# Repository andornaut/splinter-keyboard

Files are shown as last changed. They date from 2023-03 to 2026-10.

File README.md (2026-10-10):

# Splinter keyboard




A 62-key split columnar ergonomic keyboard.

This repo holds the hardware design files; firmware lives in a [separate repo](https://github.com/andornaut/qmk_firmware/tree/splinter/keyboards/splinter). Design pipeline: Keyboard Layout Editor -> Ergogen -> KiCad -> fabrication -> Onshape -> OrcaSlicer -> QMK (see [Developing](#developing)).

Related notes: [3D printing](https://github.com/andornaut/til/blob/main/docs/3d-printing.md), [electronics](https://github.com/andornaut/til/blob/main/docs/electronics.md), [keyboards](https://github.com/andornaut/til/blob/main/docs/keyboards.md).

## Versions

| Version | MCU | Changes from previous | Firmware | Photo |
| --- | --- | --- | --- | --- |
| [v4](./v4) | [splitkb Liatris](https://splitkb.com/products/liatris) (RP2040) | Added USB VBUS detection and TRRS data-line protection | [splinter](https://github.com/andornaut/qmk_firmware/tree/splinter/keyboards/splinter) | Pending |
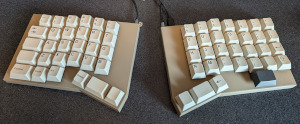
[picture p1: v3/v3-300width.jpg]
v3
| [v3](./v3) | [Adafruit KB2040](https://www.adafruit.com/product/5302) (RP2040) | Switched from AVR to RP2040 | [splinter-3.0](https://github.com/andornaut/qmk_firmware/tree/splinter-3.0/keyboards/splinter) |  |
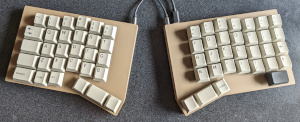
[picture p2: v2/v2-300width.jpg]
v2
| [v2](./v2) | [SparkFun Pro Micro](https://www.sparkfun.com/sparkfun-qwiic-pro-micro-usb-c-atmega32u4.html) (ATmega32U4) | Symmetrical enclosures; added a key (62 keys) | [splinter-2.0](https://github.com/andornaut/qmk_firmware/tree/splinter-2.0/keyboards/splinter) |  |
| [v1](./v1) | [SparkFun Pro Micro](https://www.sparkfun.com/sparkfun-qwiic-pro-micro-usb-c-atmega32u4.html) (ATmega32U4) | Initial version: 61 keys, columnar layout, asymmetrical enclosures | [splinter-1.0](https://github.com/andornaut/qmk_firmware/tree/splinter-1.0/keyboards/splinter) | v1 |

## Repository layout

Every version directory (`v1/` .. `v4/`) follows the same shape, though not every version has every part:

| Path | Contents |
| --- | --- |
| `ergogen/config.yaml` | Keyboard definition. The source of truth for everything downstream. |
| `ergogen/footprints/` | Symlink to the shared footprints below, so every version builds against one pinned set. Do not edit. |
| `keyboard-layout-editor/` | Layout prototypes. |
| `kicad/unrouted/` | Working boards. Ergogen generates into these; you route here. |
| `kicad/routed/` | Routed masters. The fab source. |
| `kicad/unrouted-backups/` | Timestamped copies of the `unrouted/` boards, taken each time fresh ones overwrite them. Gitignored, and only the last few per board are kept. |
| `kicad/jlcpcb-parts.json` | LCSC part numbers, kept outside the `.kicad_pcb` so they survive regeneration. v4 only, and what makes assembly files appear. |
| `onshape/` | Case design. v1 to v3 keep their exported STEP here. v4 commits none, carrying the build sheet, the rationale, and a script that builds the same design as geometry; generate or export to `dist/`. |
| `orcaslicer/` | Slicer projects. v2 and v3 only. |

Shared across versions:

| Path | Contents |
| --- | --- |
| `ergogen/` | Footprints and helpers. |
| `scripts/` | Build steps. |
| `dist/` | Build output. Generated, not committed. |

A `_` prefix on a PCB filename excludes it from every step.

## Installation

| Tool | Needed for |
| --- | --- |
| [KiCad 10](https://www.kicad.org) | Routing, and `kicad-cli` for gerber export and headless DRC |
| [Node.js](https://nodejs.org/en) | Ergogen and the npm scripts |
| [Python 3](https://www.python.org) | The build steps (stdlib only; `pcbnew` comes from KiCad) |
| [OrcaSlicer](https://github.com/OrcaSlicer/OrcaSlicer) | Slicing the printed case |
| [FreeCAD](https://www.freecad.org) | `freecadcmd`, for [validating the case export](#step-6-onshape) |
| [Freerouting](https://github.com/freerouting/freerouting) | Optional, for [autorouting](#autorouting-optional) |
| [KiKit](https://github.com/yaqwsx/KiKit) | Optional, for [panelization](#panelization-optional-for-pcba-cost); needs the git-master build |

```bash
# Include submodules when cloning
git clone --recursive git@github.com:andornaut/splinter-keyboard.git
cd splinter-keyboard

# Install the Node version from .nvmrc, then the deps (including Ergogen)
nvm install
npm install

# Install KiCad 10 (provides kicad-cli, used for fab file generation)
sudo add-apt-repository ppa:kicad/kicad-10.0-releases
sudo apt install kicad

# Fallback only if you cloned without --recursive
git submodule update --init --recursive
```

OrcaSlicer, FreeCAD, KiCad, Freerouting and KiKit also install from [these Ansible tasks](https://github.com/andornaut/ansible-ctrl/blob/main/roles/hobbies/tasks/main.yml) (tags `orcaslicer`, `freecad` and `kicad`; Freerouting and KiKit come with `kicad`).

**Updating footprint submodules.** `npm run ergogen` uses `ceoloide` and `infused-kim` at their pinned revision and never advances them, so builds stay reproducible. To re-pin:

```bash
git submodule update --remote ergogen/footprints/ceoloide ergogen/footprints/infused-kim
git add ergogen/footprints/ceoloide ergogen/footprints/infused-kim
git commit -m "Bump footprint submodules"
```

## Commands

Run everything through `npm run` from the repo root: the scripts read the active version from `config.VERSION` in [`package.json`](./package.json).

| Command | Does |
| --- | --- |
| `pipeline` | The full build, every gate in order. The normal entry point. Add `-- -v` for the full log. |
| `ergogen` | Generate outlines and PCBs into `dist/${VERSION}/ergogen/` |
| `watch` / `watch:sync-unrouted` | Re-run `ergogen` on every `config.yaml` change, the second also copying into `unrouted/` |
| `copy:dist-to-unrouted` | `dist/` -> `unrouted/` (backs the old boards up to `unrouted-backups/` first) |
| `copy:traces-to-unrouted` | Traces and teardrops from `routed/` back into `unrouted/` |
| `copy:unrouted-to-routed` | `unrouted/` -> `routed/` (see [Saving to routed/](#saving-to-routed)) |
| `fab` | Gerbers, drill, and assembly BOM/CPL via `kicad-cli` |
| `panelize` | Combine both halves into one JLCPCB panel (optional) |
| `route` | Autoroute `unrouted/` via Freerouting (optional) |
| `validate:provenance` / `validate:symmetry` / `validate:firmware` / `validate:fab` | The four gates (see [Validation](#validation)) |
| `clean` | Remove `dist/` |
| `lint` / `format` | Prettier and ESLint, checking or fixing. `lint` is a CI gate |

## Developing

### Step 1. Configure

Set `config.VERSION` in [`package.json`](./package.json) to `v1`, `v2`, `v3`, or `v4`, by editing the file or with `npm pkg set config.VERSION=v4`.

### Step 2. [Keyboard Layout Editor](https://www.keyboard-layout-editor.com/)

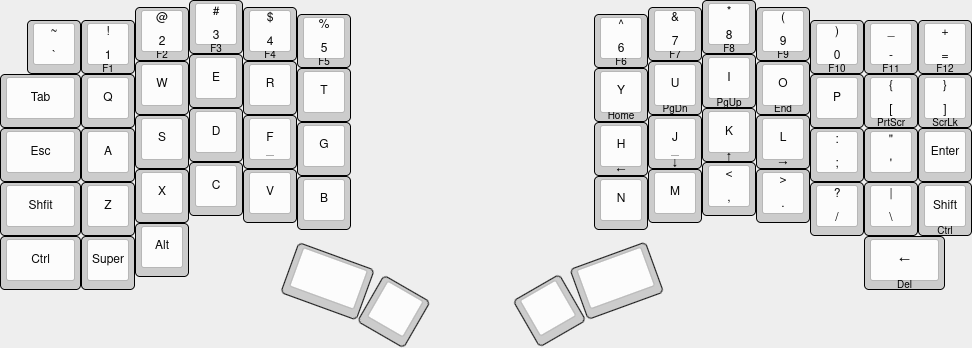
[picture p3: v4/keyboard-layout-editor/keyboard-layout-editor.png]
Keyboard Layout preview


Prototype a layout, export it to [`keyboard-layout-editor.json`](./v4/keyboard-layout-editor/keyboard-layout-editor.json) so you can re-import and iterate, then use it as the basis for the Ergogen design.

### Step 3. [Ergogen](https://github.com/ergogen/ergogen)

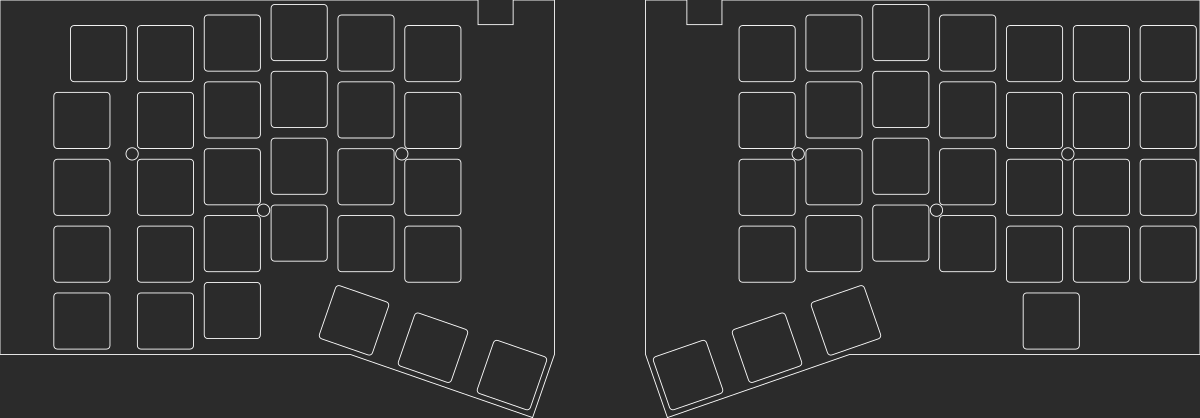
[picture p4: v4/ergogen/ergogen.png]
Ergogen preview


1. `docker compose up` starts the Ergogen GUI (it builds on first run); open <http://ergogen.internal> (needs [docker_etc_hosts](https://github.com/andornaut/docker_etc_hosts) for the `/etc/hosts` entry).
1. Paste in, edit, then download [`ergogen/config.yaml`](./v4/ergogen/config.yaml).
1. `npm run ergogen`, then `npm run copy:dist-to-unrouted`. Or just `npm run watch:sync-unrouted`.

- The GUI renders no PCBs and is client-side only. Edit there, copy back to `config.yaml` (the source of truth), build with `npm run ergogen`.
- The browser cannot load footprints from disk, so the [`Dockerfile`](./Dockerfile) bakes this repo's [custom footprints](./ergogen/footprints/) into the GUI image. An unregistered `what:` shows up as unknown; after adding one, `docker compose build --no-cache`.

### Step 4. [KiCad](https://www.kicad.org/)

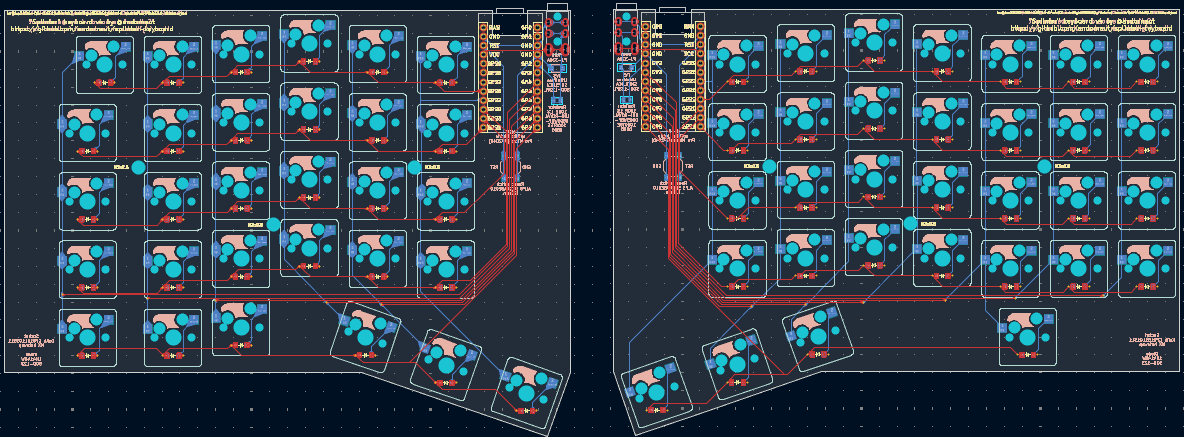
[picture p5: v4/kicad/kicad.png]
KiCad preview


Open a board from [`kicad/unrouted/`](./v4/kicad/unrouted/) and route it. Before saving:

- **Add teardrops** (Edit > Edit Teardrops, nothing selected for board-wide): stronger pad and via joints. Re-run after any reroute.
- **Run DRC** (Inspect > Design Rules Checker, "Refill all zones" checked): clear every violation and unrouted net. `npm run fab` re-runs it headlessly, but fixing it here beats reading the JSON.
- **Check copper and silk** visually: no isolated GND islands or stranded pads; silk clear of pads and the board edge.

After regenerating with Ergogen, `npm run copy:traces-to-unrouted` brings the traces and teardrops from `routed/` back into `unrouted/` (then File > Revert in KiCad).

#### Saving to routed/

`npm run copy:unrouted-to-routed` writes the masters' `.kicad_pro` and `.kicad_dru` first, since the stages that move copper measure against the clearances those hold. Then, one master at a time, it copies the working board onto its master in [`kicad/routed/`](./v4/kicad/routed/) and runs:

| Stage | What it does |
| --- | --- |
| GND pour | Floods a ground plane on whichever side costs less (scored per board, F.Cu vs B.Cu) |
| Cleanup | Strips copper no route uses: dangling tracks and the vias they strand, tracks buried in pads, redundant vias, split segments |
| Pattern snap | Pulls strays onto the repeated shape they belong to, within a per-endpoint cap |
| Sliver tidy  | Collapses any segment left shorter than it is wide, within a per-endpoint cap |

One master at a time, copy included, because any stage can stop the build: a master this run has not reached yet is still the routed board it was, rather than an un-poured working copy that nothing downstream would catch.

The last three stages feed each other: a collapsed sliver can leave a run the next snap recognises, and a snap leaves fragments for the next cleanup to merge and can leave a sliver of its own. So they repeat until a pass changes nothing, and a board still changing on the last allowed pass stops the build instead of shipping a master its own tooling has not finished with.

The working boards keep the stripped copper, mainly the footprints' unused `include_traces_vias` stubs, since a later reroute may pick it up.

Pattern snap and sliver tidy move copper rather than only removing it, so both are capped and both stop the build rather than guess:

- **Pattern snap.** The matrix is a grid, so most of the routing is one motif repeated, and hand-drawn copies land a fraction of a millimetre apart. DRC never sees it, because each copy is individually legal. Anything beyond the cap is a routing decision rather than a stray, so it is reported and left alone.
- **Sliver tidy.** Moving one end of a run pivots the whole run, so a collapse is refused if it exceeds the cap or would swing copper into another net's clearance or a keepout. The refusal names the sliver and the reason; close it in KiCad by dragging the two runs together, or by re-routing clear of the named area.

#### Autorouting (optional)

KiCad has no built-in autorouter. `npm run route` routes the [`unrouted/`](./v4/kicad/unrouted/) boards in place via [Freerouting](https://github.com/freerouting/freerouting), leaving `routed/` untouched; expect to hand-clean the result, then File > Revert. Raising via cost trades vias for _unrouted nets_, so it cannot beat hand-routing on via count.

| Env var | Default | Values |
| --- | --- | --- |
| `FREEROUTING_PASSES` | 100 | |
| `FREEROUTING_STRATEGY` | greedy | greedy, global, hybrid |
| `FREEROUTING_SELECTION` | prioritized | prioritized, random, sequential |
| `FREEROUTING_VIA_COST` | 50 | higher = fewer vias |
| `FREEROUTING_UNDESIRED_DIR_COST` | unset | cost of routing against a layer's preferred direction |
| `FREEROUTING_LOG_LEVEL` | WARN | ERROR, WARN, INFO, DEBUG, TRACE |

### Step 5. Fabrication (JLCPCB)

`npm run fab` exports from `routed/` into `dist/${VERSION}/kicad/jlcpcb/<name>/`:

| Output | Contents |
| --- | --- |
| `<name>-gerber.zip` | Gerbers and drill: the bare PCB |
| `<name>-BOM.csv`, `<name>-CPL.csv` | Assembly files, written only when [`jlcpcb-parts.json`](./v4/kicad/jlcpcb-parts.json) is present |
| `<name>-drc.json` | Headless DRC report, written per board before that board's export. Any error-level violation or unrouted net stops the run there, so a failing board never overwrites its own last-good gerbers. |

A provenance check gates the whole run before any board is touched, so a master that drifted from `config.yaml` produces nothing at all.

Which parts JLCPCB places and which you hand-solder is version-specific; see the [v4 notes](./v4/README.md#fabrication-jlcpcb).

**Ordering** from [JLCPCB](https://jlcpcb.com/): upload each `<name>-gerber.zip`, plus the matching BOM and CPL for assembly. Check placement in the [DFM viewer](https://cart.jlcpcb.com/quote/gerberviewThree); fix a mis-oriented part via its `rotation` in [`jlcpcb-parts.json`](./v4/kicad/jlcpcb-parts.json) and re-run.

#### Panelization (optional, for PCBA cost)

`npm run panelize` combines `left` and `right` into one panel so JLCPCB's per-order assembly setup and stencil fees are paid once instead of twice: worth it for PCBA orders, skip it for bare boards. Outputs to `dist/${VERSION}/kicad/jlcpcb/panel/`; the per-half `fab` remains the strict DRC gate. Requires [KiKit](https://github.com/yaqwsx/KiKit) (git-master build for KiCad 10); point it at an interpreter with `KIKIT_PYTHON`.

### Step 6. [Onshape](https://cad.onshape.com)

1. Create a document and start a sketch.
1. Select "Insert a DXF or DWG file" > "Import ..." (bottom of the dialog) > `dist/${VERSION}/ergogen/outlines/full_unfilleted.dxf`. That is the nominal hull rather than the fabricated edge: the fillet only removes material, so a pocket cut to the hull can never come out undersized.
1. Design the case to [`onshape/BUILD.md`](./v4/onshape/BUILD.md), which carries every dimension and the feature-by-feature recipe, then export `*.step` files to `dist/${VERSION}/onshape/`. They are build output and are not committed, so a stale one cannot sit in the repo looking like the thing to order.
1. Validate each half's export against the reference, `FC_HALF=left FC_COMPARE=dist/${VERSION}/onshape/<export>.step freecadcmd v4/onshape/gen-case.py`, and decide every difference it reports: move the model to the reference, record it in `v4/onshape/differences.json` as intentional, or fix it as an error. See [Validating your model](./v4/onshape/BUILD.md#validating-your-model).

### Step 7. [OrcaSlicer](https://github.com/OrcaSlicer/OrcaSlicer)

1. Open or create a project and import the `*.step` files from `dist/${VERSION}/onshape/`.
1. Slice and print the case.
1. Install an [M2.5 heat-set insert](https://cnckitchen.store/products/gewindeeinsatz-threaded-insert-m2-5-standard-100-stk-pcs) into each mounting boss with a soldering iron, then clamp the PCB with the [M2.5 screws](./v4/README.md#bill-of-materials-bom).

#### Alternative: machined aluminium case (JLCCNC)

Upload each half's `*.step` to [JLCCNC](https://jlccnc.com) (left and right are separate mirrored parts, so set quantity per file):

| Setting | Value |
| --- | --- |
| Material | 6061 aluminium (JLCCNC's standard alloy) |
| Surface finish | Bead blasting + matte anodizing; drop the bead blasting for a glossier sheen. Black is the safe color. |
| Tolerance | Default (ISO 2768 medium) |
| Threaded holes | Tap the M2.5 holes directly; the heat-set inserts are for the printed case only |

A STEP file cannot carry threads, so model each hole at the ~2.05mm tap-drill diameter and upload a PDF with an `M2.5x0.45` callout and depth. Every hole shares the thread spec, but not the depth: the two bosses a switch recess overlaps take a shallower hole, so call the depths out per boss from the [build sheet](./v4/onshape/BUILD.md#screw-bosses). In Onshape, a Drawing with a hole callout (right-click the hole edge > Callout) emits it.

### Step 8. [QMK firmware](https://qmk.fm/)

Install the [custom QMK firmware](https://github.com/andornaut/qmk_firmware/tree/splinter/keyboards/splinter).

## Automation

### One-command pipeline

`npm run pipeline` re-syncs already-routed boards after a config change:

| # | Step | Does |
| --- | --- | --- |
| 1 | `ergogen` | Rebuild the boards from `config.yaml` |
| 2 | `copy:dist-to-unrouted` | Fresh boards into `unrouted/`, old ones backed up |
| 3 | `copy:traces-to-unrouted` | Replay the masters' routing onto them |
| 4 | `copy:unrouted-to-routed` | Save back to `routed/` ([details](#saving-to-routed)) |
| 5 | `validate:provenance` | Stamps match `config.yaml` |
| 6 | `validate:symmetry` | The halves are exact mirror images |
| 7 | `validate:firmware` | Boards match the QMK matrix |
| 8 | `fab` | Export gerbers and assembly files |
| 9 | `validate:fab` | Audit those outputs |

Every step is a hard gate. `panelize` runs last and is the only optional one, skipped with a note when KiKit is absent.

A step reports what it changed and what wants reading; lines that only confirm nothing needed doing are held back, since each step's closing `OK:` line already carries the count they would have added up to. `npm run pipeline -- -v` shows them all, plus Ergogen's own narration and the artifact listing file by file.

**It requires existing routed masters** and does not route for you: step 3 replays their traces onto the fresh boards and aborts if a master carries no human routing. For a first route, or when geometry moves enough that the old traces no longer fit, route by hand in KiCad (Step 4).

### Validation

| Gate | Checks |
| --- | --- |
| `validate:provenance` | Every board's stamp still matches `config.yaml`, and the boards in a stage were all built in the same run, so neither a stale master nor a half restored on its own can reach fab |
| `validate:symmetry` | The two halves are exact mirror images: outline, parts, pads, rule areas and silk, compared in each board's own frame so the per-board recentering is not read as asymmetry |
| `validate:firmware` | Both halves wire the MCU header identically, and the matrix they imply equals the QMK `keyboard.json` |
| `validate:fab` | The exported artifacts: a board-spanning GND plane on both master and gerbers, a complete gerber set, a non-empty BOM and CPL with every assembled footprint appearing in the CPL exactly once, outputs no older than their sources, comparable teardrop counts across the halves |

`validate:fab` also warns, without failing, when a master was built from an uncommitted tree: the board is fine, but its recorded commit means nothing, so the warning is expected during ordinary in-progress work.

`validate:symmetry` holds the halves to being exact mirrors of each other. The licensed exception is the keys of the outer pinky columns, which differ by design (the left pinky is 1.5u; the right is 1u plus an extra inner column). Drift here is otherwise invisible: both halves still route, pass DRC, fab and assemble, and it surfaces only as a case that fits one half and rocks on the other, or a clearance that is comfortable on one half and marginal on the other. Both halves are generated from one set of mirrored anchors in `config.yaml`, so a failure is a config change to undo rather than a board to edit.

Three kinds of part are placed in the same orientation on both halves rather than mirrored, because the parts themselves cannot be: an MX switch and its Kailh socket have an asymmetric pin pattern, the matrix diode wires straight to a switch pin and follows it, and the MCU is a module that plugs in one way up. Their pads therefore land at mirrored positions carrying the opposite pin at each. Key _placements_ still mirror exactly, and so does every clearance measured from key geometry; only pad-to-edge distances within a key differ between the halves. Hand routing is not compared at all.

`validate:firmware` reads the `keyboard.json` at `config.FIRMWARE` in [`package.json`](./package.json), which ships as a path to a sibling `qmk_firmware` checkout so the check covers what you are about to flash rather than what is pushed. Without that checkout the step fails and no gerbers are produced; pass `--firmware <url|path>` or set `$SPLINTER_FIRMWARE_JSON` instead.

### Provenance stamp

The copy steps and manual routing let `routed/` drift from `config.yaml`, so you could fab a stale board. `npm run ergogen` stamps each board with a hash of `config.yaml`; `fab` refuses a drifted or unstamped master, and `validate:provenance` checks without fabbing. Clear a mismatch by re-running the pipeline, re-routing if needed.

Restoring or rebuilding one half on its own is invisible to the hash, since identical config bytes hash the same across builds, so `validate:provenance` also requires every board in a stage to carry the same stamp. The two stages are compared separately: `unrouted/` is expected to be newer than `routed/` between an `ergogen` run and the save back to the masters.

A panel inherits its masters' stamp rather than getting one of its own, so its `commit=` names the commit the panelled copper came from. Masters whose stamps disagree stop `panelize`, since a panel merged from two generations of board has no single provenance to report.

Only `config.yaml` is hashed, so a footprint `.js` or Ergogen-version change can move geometry without tripping the check, while a comment-only config edit trips a false "stale".

### Reproducing a previous build

A stamp names the commit the build's _inputs_ came from, never the commit that contains the stamped board: the stamp is written into the board, so it can only name its own parent. To get the boards a stamp describes, check that commit out and rebuild.

```bash
git checkout <the commit= from the stamp>
npm run pipeline
```

Taking `kicad/routed/*.kicad_pcb` straight from that commit instead gives you the _previous_ build's masters. Rebuilding reproduces copper, drill, mask, paste, outline and the assembly files identically; only the `built=` timestamp drawn on the silk and a few microns of teardrop fill tessellation differ.

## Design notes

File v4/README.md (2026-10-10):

# Version 4 of the Splinter keyboard

A 62-key split columnar ergonomic keyboard with symmetrical enclosures and non-traditional backspace and backslash placement.

- [QMK firmware](https://github.com/andornaut/qmk_firmware/tree/splinter/keyboards/splinter)
- Build and fabrication workflow: [root README](../README.md#developing)

Each PCB half:

| Outline | Width | Height |
| --- | --- | --- |
| Un-filleted hull | 160.00 mm | 119.00 mm |
| As fabricated, after the 1.5mm corner fillet | 160.00 mm | 118.59 mm |

The fillet rounds the corners off the height; the straight side edges hold the width. See the [case design notes](./onshape/README.md).

## Changes from v3

| Change | Details |
| --- | --- |
| The [splitkb Liatris](https://splitkb.com/products/liatris) (RP2040) replaces the [Adafruit KB2040](https://www.adafruit.com/product/5302) MCU | [Microcontroller](#microcontroller) |
| A TVS diode and series resistor protect the TRRS serial line from hot-unplug transients | [TRRS data-line protection](#trrs-data-line-protection) |

## Microcontroller

The [splitkb Liatris](https://splitkb.com/products/liatris) wires its USB VBUS line to GP19, so QMK senses USB presence via `USB_VBUS_PIN` instead of the `SPLIT_USB_DETECT` polling loop. That removes the roughly two-second unresponsive window at boot and makes the board more reliable after KVM switches.

The MCU is socketed rather than soldered: each one sits in a pair of Mill-Max 12-pin sockets (see the [BOM](#bill-of-materials-bom)) so it can be removed and reused. It mounts on the bottom of the board, the same side as the diodes, hotswap sockets and the rest of the SMD parts, with its own components facing away from the board so the reset and boot buttons stay reachable. That seating determines which header column each matrix net lands on, so it is not interchangeable with the opposite orientation.

The matching firmware config (the `USB_VBUS_PIN` define and the `development_board` and split settings) lives in the [firmware repo](https://github.com/andornaut/qmk_firmware/tree/splinter/keyboards/splinter).

### Pinout

- [splitkb Liatris pinout](https://docs.splitkb.com/product-guides/liatris/pinout)
- [Custom Ergogen footprint: `mcu_liatris`](../ergogen/footprints/mcu_liatris.js), based on [ceoloide/mcu_nice_nano](../ergogen/footprints/ceoloide/mcu_nice_nano.js) and the [marbastlib KiCad footprint](https://github.com/ebastler/marbastlib)

| Left | | | Right |
| --- | --- | --- | --- |
| P1 (GP0) | | | RAW |
| P0 (GP1) | | | GND |
| GND | | | RST |
| GND | | | VCC |
| P2 (GP2) | | | P21 (GP29) |
| P3 (GP3) | | | P20 (GP28) |
| P4 (GP4) | | | P19 (GP27) |
| P5 (GP5) | | | P18 (GP26) |
| P6 (GP6) | | | P15 (GP22) |
| P7 (GP7) | | | P14 (GP20) |
| P8 (GP8) | | | P16 (GP23) |
| P9 (GP9) | | | P10 (GP21) |

The Liatris also carries five extra bottom pins (GP12 to GP16) that the footprint can place but the matrix does not use.

GP19, the `USB_VBUS_PIN`, is the Liatris's internal VBUS-sense pin rather than a header net, so it is absent from the table. The `P19` row maps to GP27, a separate matrix pin.

Which column is which is set by one parameter, `raw_pin_column` on the [`mcu_liatris`](../ergogen/footprints/mcu_liatris.js) footprint: `front_left` or `front_right`, named from the PCB front. [ergogen/config.yaml](./ergogen/config.yaml) sets it explicitly to `front_right`, the footprint's default. From the back, where the MCU mounts, the columns read the other way round. The table above is `front_right`, the datasheet arrangement. Both halves must share the value, because the Liatris cannot be mirrored.

To check it on a physical board, seat the module and confirm its RAW pin lands on the pad silkscreened RAW. The board silk and the config net names cannot tell you: they move together when the parameter flips.

### Verifying the pin mapping

A board whose matrix nets reach the wrong MCU column is fully routed, shorts nothing, and passes DRC and every other check here. It fails only once an MCU is plugged in, which is after the boards are paid for. `npm run validate:firmware` is the gate for that, and both of its checks are required:

- **Half symmetry.** Both halves must wire the MCU header identically. Halves that disagree mean one of them is backwards.
- **Firmware agreement.** The matrix pins implied by the boards must equal the QMK [keyboard.json](https://github.com/andornaut/qmk_firmware/blob/splinter/keyboards/splinter/keyboard.json), both halves plus the serial pin.

What the checks guarantee is that the two halves agree and that the config's net assignments never silently drift from the firmware's pin arrays. What they cannot prove is that the mapping matches physical reality: both mirrorings of the header produce electrically valid boards, the footprint's silk pin labels are generated from the same table as the pad nets, and the firmware check compares net names through that same table. All three move together under a `raw_pin_column` flip.

Only hardware settles that, and it is settled: the current value, `front_right`, is confirmed on an assembled and working board. Treat it as fixed. Changing it, or changing how the MCU seats, invalidates that confirmation and needs a fresh check on hardware.

## TRRS data-line protection

v4 adds a TVS diode and series resistor on the TRRS data line to protect the MCU's serial GPIO when the cable is hot-unplugged. Each half:

```text
TRRS Ring 2 --(DATA_RAW)--+-- 100Ω --(P2)-- MCU GP2
                          |
                         TVS (clamps to GND)
                          |
                         GND
```

| Part | Role |
| --- | --- |
| TVS (bidirectional, 5V standoff) | Clamps the line to GND. Its 5V turn-on stays above the 3.3V data signal, so it does not conduct in normal use, and it clamps to roughly 9V under surge. |
| 100Ω series resistor | Limits current into the MCU pin. |

The connector pinout also changed: **GND on the sleeve, serial data on ring R2, VCC on the tip.** The sleeve breaks last when you unplug, so the halves keep a common ground through the disconnect, and the data line sits on an inner ring instead of the exposed tip.

Neither change affects firmware: the data line still terminates at the MCU serial pin, GP2.

## Copper keepout zones

`npm run ergogen` adds copper keepout rule areas to the generated boards. They ride the copy steps into `unrouted/` and `routed/` automatically. Do not hand-edit them.

| Zone | Excludes | Purpose |
| --- | --- | --- |
| Perimeter pour ring  | The GND pour | Keeps the plane off the whole board edge. A ring just inside the edge, sized to clear the case support-wall lip, bridged straight across the USB cutout. |
| Perimeter route ring | Tracks, vias, conductive pads | Same ring, minus a carved-out band above the TRRS: the case's top wall has the port opening there, so the TRRS top through-holes may reach the edge. The inner vertical edge stays full height, so copper under the side wall is still flagged. |
| Screw-boss disks | Pour, tracks, vias | One disk per mounting hole, extending past the boss edge by the margin the script sets. |

Bare mechanical (NPTH) holes, meaning the mounting holes and the TRRS locating hole, carry no copper and are always allowed. The conductive-pad check is a custom DRC rule in each board's `<name>.kicad_dru`; it keys on pad type, so SMD lands like the hotswap sockets are caught too.

## Bill of materials (BOM)

| Description | Quantity | Part |
| --- | --- | --- |
| Diodes | 62 | [1N4148W](https://www.lcsc.com/product-detail/C81598.html) (C81598, SOD-123 switching; JLCPCB Basic, alt Jingdao C115103) |
| Hot swap sockets | 62 | [Adafruit 4958](https://www.digikey.ca/en/products/detail/adafruit-industries-llc/4958/13997772) (Kailh CPG151101S11 MX hotswap socket; DigiKey 1528-4958-ND, 20/pack) |
| Keycap set | 1 | [GMK CYL Sixes keycaps](https://www.deskhero.ca/products/gmk-sixes-keycaps-extras) and [Ergo Kit](https://www.deskhero.ca/products/gmk-sixes-keycaps-extras?variant=40182207676482) |
| Key switches | 62 | [Cherry MX Ergo Clear](https://shockport.ca/collections/switches-1/products/cherry-mx-ergo-clear) |
| Microcontrollers | 2 | [splitkb Liatris](https://splitkb.com/products/liatris) (RP2040) |
| Resistors | 2 | [100Ω 0805 1%](https://www.lcsc.com/product-detail/C17408.html) (C17408, UNI-ROYAL 0805W8F1000T5E; JLCPCB Basic, alt YAGEO C105577) |
| Screws | 6 | M2.5 button head, ISO 7380 (one per boss, 3 per half). The sloped plate puts the three standoffs at different heights, so two lengths are needed: 4 x 10mm and 2 x 11mm, per boss in the [case build sheet](./onshape/BUILD.md#screw-bosses) |
| Silicon bumpers | 8 | [10x2mm Silicone Rubber Bumpers](https://www.aliexpress.com/item/1005005315398342.html) |
| Sockets (12-pin) | 4 | [Mill-Max 315-43-112-41-003000](https://www.mouser.ca/ProductDetail/575-3154311241003000) ([series documentation](https://mm.digikey.com/Volume0/opasdata/d220001/medias/docus/2481/310%2C%20311%2C%20315%20Series%20%28in.%29.pdf)) |
| Socket pins | 48 | [Mill-Max 3320-0-00-15-00-00-03-0](https://www.mouser.ca/ProductDetail/575-3320000150000030) |
| Switches/buttons (reset) | 2 | [5.2mm SMD tact switch](https://www.lcsc.com/product-detail/C115351.html) (C115351, ALPS SKQGABE010; JLCPCB Extended, alt ALPS SKQGAFE010 C202424; hand-soldered) |
| Threaded inserts | 6 | [M2.5 threaded inserts](https://cnckitchen.store/products/gewindeeinsatz-threaded-insert-m2-5-standard-100-stk-pcs) (one per boss, 3 per half; 3.6mm hole, bore depth per boss in the [case build sheet](./onshape/BUILD.md#screw-bosses)) |
| TRRS cables | 1 | [King Cables TRRS Cable](https://www.kingcables.org/) |
| TRRS jacks | 2 | [HCTL HC-PJ-320A-4P-D](https://www.lcsc.com/product-detail/Audio-Connector-Headphone_HCTL-HC-PJ-320A-4P-D_C5372851.html) |
| TVS diodes | 2 | [Littelfuse SMF5.0CA](https://www.lcsc.com/product-detail/C1851363.html) (C1851363, SOD-123FL bidirectional, 5V standoff; JLCPCB Extended; alt MDD C364279, TWGMC C726939) |

## Fabrication (JLCPCB)

See the root README's [fabrication step](../README.md#step-5-fabrication-jlcpcb) for how `npm run fab`, the DRC gate, and [jlcpcb-parts.json](./kicad/jlcpcb-parts.json) work. This section covers only what is v4-specific.

| Part | Assembly |
| --- | --- |
| Matrix diodes, 100Ω data-line resistor, TVS | Placed by JLCPCB |
| Hotswap sockets | Do-Not-Place. Keeping them off the assembly BOM is what holds the order on the cheaper **Economic** PCBA service: they are Standard-only and not stocked for JLC assembly. |
| MCU (Liatris), TRRS jack, reset switch | Do-Not-Place, hand-soldered |

The LCSC and vendor links in the [BOM](#bill-of-materials-bom) for Do-Not-Place parts are for sourcing only.

The diode footprint (`diode_sod123`) carries `rotation: 180` in [jlcpcb-parts.json](./kicad/jlcpcb-parts.json) so the cathode band lands on pad 1, the cathode and row net. The resistor and TVS are non-polar, so their rotation is irrelevant. After uploading, confirm orientation in JLCPCB's DFM viewer.

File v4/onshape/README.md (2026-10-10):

# v4 case design (Onshape)

Case models live here. The case is modelled from the Ergogen outline
(`dist/v4/ergogen/outlines/full_unfilleted.dxf`), then printed (OrcaSlicer) or CNC-machined
(JLCCNC). See the root `README.md` steps 6-7 for the import and order workflow.

Each file has one job:

| File | Holds |
| --- | --- |
| [BUILD.md](./BUILD.md) | Every dimension, and the feature-by-feature recipe for Onshape |
| [gen-case.py](./gen-case.py) | The same design as geometry, and the validator for the hand-built model |
| [differences.json](./differences.json) | The hand-built model's intentional departures from that geometry |
| This file | Why the design is shaped the way it is. **No numbers**, so it cannot drift |

**No STEP is committed here.** A STEP in the repo reads as the thing to order from, and
nothing about the file says how far behind the design it is. Onshape exports go to
`dist/v4/onshape/`, to be validated and ordered from.

## Generating a model

```bash
npm run ergogen                     # the DXF this reads
freecadcmd v4/onshape/gen-case.py
```

Writes both halves to `dist/v4/onshape/`, then reads each file back and checks it before
exiting. Options come from the environment, since `freecadcmd` treats trailing arguments as
documents to open:

| Variable | Default | Effect |
| --- | --- | --- |
| `FC_HALF` | `both` | `left`, `right` or `both` |
| `FC_EXPLODE` | `0` | mm to drop the plate by, for viewing the cavity |
| `FC_DXF` | the Ergogen hull | source outline |
| `FC_OUTDIR`  | `dist/v4/onshape`  | destination |
| `FC_COMPARE` | unset | your Onshape export(s) of one half, to validate |
| `FC_DIFFS` | `differences.json` | recorded intentional differences |

Output is solid B-rep, not a mesh, so curved features measure their nominal size and the
result can be sketched against. The self-check reads the exported file rather than the
shape in memory, because **a STEP can carry valid geometry and still import as nothing**
if its product structure is missing, which is the failure it exists to catch.

This is the reference and the validator, not the master. The master is the Onshape
document, built by hand from BUILD.md. With `FC_COMPARE` set, the script compares an export
of it against the reference and fails on every difference not recorded in
`differences.json`. Each difference is decided one of three ways: move the model to the
reference, record it as intentional, or fix it as an error. The procedure is in
[BUILD.md](./BUILD.md#validating-your-model).

The script's guards catch the defects a closed, correctly sized solid can still carry, so
the comparison extends them to the hand-built model everywhere it matches the reference.

## What the case takes from the board, and what it does not

- **Model to the un-filleted hull.** The fillet cuts convex corners back, so the hull
  contains the fabricated edge and a pocket cut to it cannot come out undersized. The board
  then sits with a little corner gap, which is clearance rather than slop: the shelf and the
  plate's wall bear on the flat margin along every straight edge, not at the corners.
- **Measure the cut line**, KiCad's board outline polygon, not the board bounding box. The
  box is inflated by the `Edge.Cuts` stroke on every side.
- **Nothing follows the board's USB notch.** Not the outer profile, not the cavity, not the
  plate. That notch clears the plug's overmold, which sits below the board entirely, so to
  the case it is only a bite out of an edge that should run straight. The top edge is
  straight and both ports are simply openings in the back wall.
- **The outline mirrors; the switch cutouts do not.** Both halves' outer edges come from the
  same mirrored anchors, so the shell can be modelled once and mirrored. The key field
  cannot be: the left pinky is 1.5u where the right is 1u plus an extra inner column, so the
  halves carry different cutout counts and many positions have no counterpart. **Cut each
  half's switch openings from its own half of the DXF**, which is why the export carries
  both. Export every part as its own file, since JLCCNC quantity is per file.

## Topology: shell plus bottom plate

Each half is a **shell**, top face and side walls in one piece with the switch openings in
the top, closed by a separate **bottom plate**. The cavity then opens to exactly one face,
which is what both FDM and 3-axis CNC want, and screws enter from below so their heads land
in the plate.

The switch openings are **nested**: a wider recess at the top face over the plate cutout, so
each switch drops in and the surrounding top wall covers its lower body. That look is
inherently wider at the top, so nothing reaches it from below and the machined variant takes
a second setup for the recesses alone. There is no separate switch plate; the shell's top
face is the plate.

**The board is clamped around its whole perimeter**, between a shelf hanging from the case's
top and a matching wall rising from the plate, with the bosses and standoffs doing the same
at the three screw points. Both land on the board's outer keepout ring, which exists for
exactly this, so neither bears on a ground plane. Tracks are a different matter: the route
ring is deliberately carved open over the TRRS so the jack's through-holes are not flagged,
so the shelf can cross copper there, under soldermask.

**The plate's wall stops short of the top-inner corner.** Everything that hangs below the
board is there, the MCU and the jack, and so are both ports. A wall running the full
perimeter would sit on the jack's body and block both plugs.

**Which side the shelf sits on decides whether it can be made.** Above the board, pressed up
against, it narrows the opening going up and a mill reaches it from below without trouble.
Below the board, rested down on, it would put the full-width board pocket above a narrower
lip: an undercut no setup reaches, and equally impossible to print, since the board also
goes in from below.

## Printed case (OrcaSlicer)

- Print the shell top-face-down. Walls, bosses and standoffs then rise from a flat first
  layer and nothing needs support. The outer edge bezel is the one place the part flares
  outward, shallowly enough to print unsupported. It does not move elephant's foot, since
  the first layer IS the top face and its perimeter IS the visible top edge; what it does
  is set that perimeter inboard of the widest section, so first-layer squish can no longer
  stand proud of the outer profile.
- Mounting holes take heat-set inserts, so size them for the insert's melt diameter, not a
  tap.
- **Expect the switch recesses to come out tight.** FDM holes shrink, and the recess locates
  the switch, so open them up on the print and settle the figure on a coupon before
  committing a whole shell. The same goes for the plate's fit clearance.
- Port openings are holes in a vertical wall, so their top edges bridge. Chamfer or teardrop
  them if they sag.
- The silicone bumpers mount on the plate's outer face; leave a shallow recess for each,
  clear of the screw heads.

## CNC case (JLCCNC, 6061/6063 aluminium)

A mill removes material with a round tool. Every feature has to be reachable by a
cylindrical end mill from one of the setups.

1. **Internal corners carry the tool radius**, so the cavity's corners are specified as a
   _maximum_ rather than a minimum: too large a tool leaves material where the board goes.
   Do not let a shop substitute a bigger end mill.
2. **No true internal cavities and no undercuts.** Cutting from below, a feature may narrow
   going up but never widen. A chamfer or rebate at the rim is fine; a lip under the board
   pocket is not.
3. **Ports need their own setup.** Both are holes through a vertical wall, which a 3-axis
   mill reaches from neither above nor below. A right-angle head folds it back into the
   first setup if the shop has one.
4. **Model tapped holes at the tap drill**, without modelled threads, and put the thread
   callout on a 2D PDF for JLCCNC. Every hole shares the thread spec, but the depths differ
   where a switch recess overlaps a boss, so the callout has to give them per boss.
5. **Add clearance at the port openings.** CNC tolerance is tight, so a slip-fit modelled
   opening can come out too snug.
6. **Chamfers over fillets on top edges**: a chamfer is one pass with a chamfer mill,
   while a top-edge fillet needs a separate ball or profiling operation. The outer edge
   bezel rides along in the setup that cuts the switch recesses, so it costs almost
   nothing.
7. **Prefer through holes to blind**, and keep pocket depth modest relative to tool
   diameter.

**Print and assemble a half before ordering aluminium.** The printed part settles switch
seating, MCU clearance and the port openings for a few hours of filament, and aluminium is
far more expensive to get wrong.

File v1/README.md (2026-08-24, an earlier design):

# Version 1 of the Splinter keyboard

- [QMK firmware](https://github.com/andornaut/qmk_firmware/tree/splinter-1.0/keyboards/splinter)

A 61-key split columnar ergonomic keyboard with asymmetrical enclosures and a traditional key layout. Production ready.

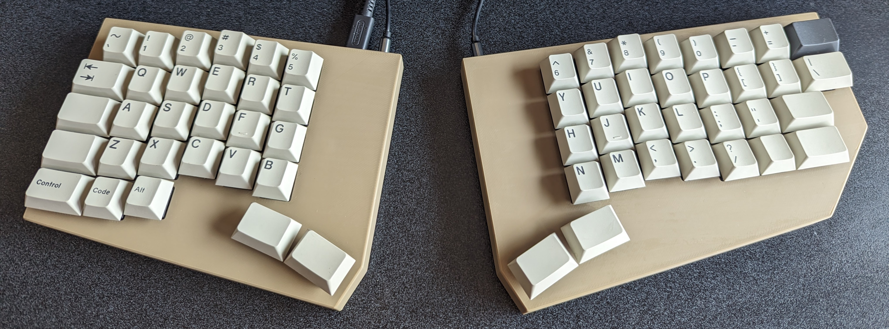
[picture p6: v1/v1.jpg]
v1


## Bill of materials (BOM)

| Description | Quantity | Part |
| --- | --- | --- |
| Diodes | 61 | [Nexperia BAS16H,115](https://www.lcsc.com/product-detail/Switching-Diode_Nexperia-BAS16H-115_C130413.html) |
| Hot swap sockets | 61 | [Kailh CPG151101S11-16](https://www.lcsc.com/product-detail/Mechanical-Keyboard-Shaft_span-style-background-color-ff0-Kailh-span-CPG151101S11-16_C5156480.html) |
| Keycap set | 1 | [GMK Sixes keycaps](https://www.deskhero.ca/products/gmk-sixes-keycaps-extras) and [Ortho Kit](https://www.deskhero.ca/products/gmk-sixes-keycaps-extras) |
| Key switches | 61 | [Cherry MX Ergo Clear](https://shockport.ca/collections/switches-1/products/cherry-mx-ergo-clear) |
| Microcontrollers | 2 | [SparkFun Pro Micro](https://www.sparkfun.com/sparkfun-qwiic-pro-micro-usb-c-atmega32u4.html) (ATmega32U4) ([GitHub](https://github.com/sparkfun/Pro_Micro?tab=readme-ov-file)) |
| Reset buttons | 2 | [E-Switch TL3342F450QG](https://www.lcsc.com/product-detail/Tactile-Switches_E-Switch-TL3342F450QG_C2886897.html) (Not needed if using the SparkFun microcontroller) |
| Screws | 4 | [M3x12mm screws](https://www.amazon.ca/gp/product/B01MZ3TWAF/) |
| Silicon bumpers  | 10 | [100Pcs Self Adhesive Round Silicone Rubber Bumpers](https://www.aliexpress.com/item/1005003258243932.html) |
| Sockets (12-pin) | 4 | [Mill-Max 315-43-112-41-003000](https://www.mouser.ca/ProductDetail/575-3154311241003000) |
| Socket pins | 48 | [Mill-Max 3320-0-00-15-00-00-03-0](https://www.mouser.ca/ProductDetail/575-3320000150000030) |
| Threaded inserts | 4 | [M3x3mm (short) threaded inserts](https://cnckitchen.store/products/heat-set-insert-m3-x-3-short-version-100-pieces) |
| TRRS cables | 1 | [Monoprice Onyx TRRS Cable](https://www.monoprice.com/product?p_id=18632) |
| TRRS jacks | 2 | [HCTL HC-PJ-320A-4P-D](https://www.lcsc.com/product-detail/Audio-Connector-Headphone_HCTL-HC-PJ-320A-4P-D_C5372851.html) |

## Microcontroller

- [Pro Micro pinout](https://golem.hu/article/pro-micro-pinout/)

| Left Arduino | Left AVR | Right Arduino | Right AVR |
| --- | --- | --- | --- |
| 1 (TX0) | D3 | RAW | |
| 0 (RX1) | D2 | GND | |
| GND | | RST | |
| GND | | VCC | |
| 2 (SDA) | D1 | A3 (21) | F4 |
| 3 (SCL) | D0 | A2 (20) | F5 |
| 4 (A6) | D4 | A1 (19) | F6 |
| 5 | C6 | A0 (18) | F7 |
| 6 (A7) | D7 | 15 | B1 |
| 7 | E6 | 14 | B3 |
| 8 (A8) | B4 | 16 | B2 |
| 9 (A9) | B5 | 10 (A10) | B6 |

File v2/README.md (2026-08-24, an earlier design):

# Version 2 of the Splinter keyboard

- [QMK firmware](https://github.com/andornaut/qmk_firmware/tree/splinter-2.0/keyboards/splinter)

A 62-key split columnar ergonomic keyboard with symmetrical enclosures and non-traditional backspace and backslash placement.

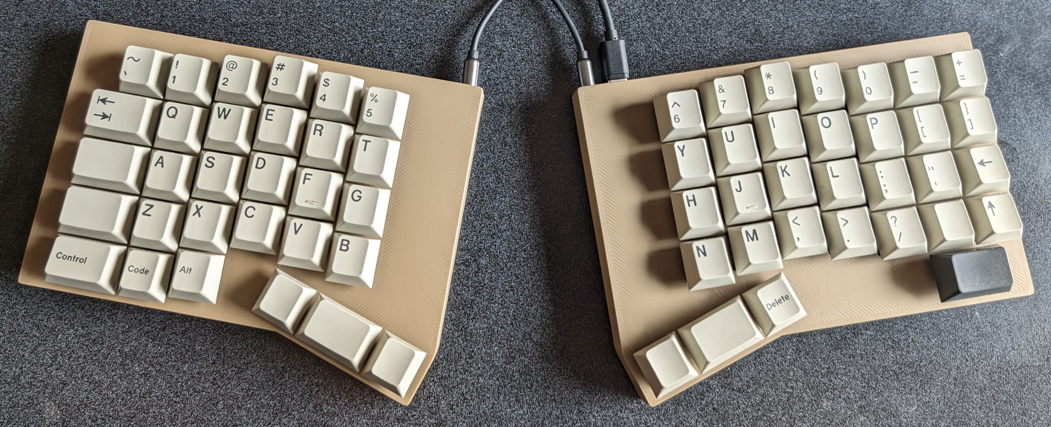
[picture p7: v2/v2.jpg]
v2


## Bill of materials (BOM)

| Description | Quantity | Part |
| --- | --- | --- |
| Diodes | 62 | [Nexperia BAS16H,115](https://www.lcsc.com/product-detail/Switching-Diode_Nexperia-BAS16H-115_C130413.html) |
| Hot swap sockets | 62 | [Kailh CPG151101S11-16](https://www.lcsc.com/product-detail/Mechanical-Keyboard-Shaft_span-style-background-color-ff0-Kailh-span-CPG151101S11-16_C5156480.html) |
| Keycap set | 1 | [GMK Sixes keycaps](https://www.deskhero.ca/products/gmk-sixes-keycaps-extras) and [Ortho Kit](https://www.deskhero.ca/products/gmk-sixes-keycaps-extras) |
| Key switches | 62 | [Cherry MX Ergo Clear](https://shockport.ca/collections/switches-1/products/cherry-mx-ergo-clear) |
| Microcontrollers | 2 | [SparkFun Pro Micro](https://www.sparkfun.com/sparkfun-qwiic-pro-micro-usb-c-atmega32u4.html) (ATmega32U4) ([GitHub](https://github.com/sparkfun/Pro_Micro?tab=readme-ov-file)) (Note that [some USB-C Pro Micros are 3mm longer](https://keeb.io/products/pro-micro-usb-c-version-5v-16mhz-arduino-compatible-atmega32u4) than the Micro-USB version that the Ergogen footprint is based on, but this is not true of the [SparkFun USB-C Pro Micro](https://www.sparkfun.com/sparkfun-qwiic-pro-micro-usb-c-atmega32u4.html)) |
| Reset buttons | 2 | [E-Switch TL3342F450QG](https://www.lcsc.com/product-detail/Tactile-Switches_E-Switch-TL3342F450QG_C2886897.html) (Not needed if using the SparkFun microcontroller) |
| Screws | 4 | [M3x12mm screws](https://www.amazon.ca/gp/product/B01MZ3TWAF/) |
| Silicon bumpers  | 8 | [100Pcs Self Adhesive Round Silicone Rubber Bumpers](https://www.aliexpress.com/item/1005003258243932.html) |
| Sockets (12-pin) | 4 | [Mill-Max 315-43-112-41-003000](https://www.mouser.ca/ProductDetail/575-3154311241003000) |
| Socket pins | 48 | [Mill-Max 3320-0-00-15-00-00-03-0](https://www.mouser.ca/ProductDetail/575-3320000150000030) |
| Threaded inserts | 4 | [M3x3mm (short) threaded inserts](https://cnckitchen.store/products/heat-set-insert-m3-x-3-short-version-100-pieces) |
| TRRS cables | 1 | [Monoprice Onyx TRRS Cable](https://www.monoprice.com/product?p_id=18632) |
| TRRS jacks | 2 | [HCTL HC-PJ-320A-4P-D](https://www.lcsc.com/product-detail/Audio-Connector-Headphone_HCTL-HC-PJ-320A-4P-D_C5372851.html) |

## Microcontroller

- [Pro Micro pinout](https://golem.hu/article/pro-micro-pinout/)

| Left Arduino | Left AVR | Right Arduino | Right AVR |
| --- | --- | --- | --- |
| 1 (TX0) | D3 | RAW | |
| 0 (RX1) | D2 | GND | |
| GND | | RST | |
| GND | | VCC | |
| 2 (SDA) | D1 | A3 (21) | F4 |
| 3 (SCL) | D0 | A2 (20) | F5 |
| 4 (A6) | D4 | A1 (19) | F6 |
| 5 | C6 | A0 (18) | F7 |
| 6 (A7) | D7 | 15 | B1 |
| 7 | E6 | 14 | B3 |
| 8 (A8) | B4 | 16 | B2 |
| 9 (A9) | B5 | 10 (A10) | B6 |

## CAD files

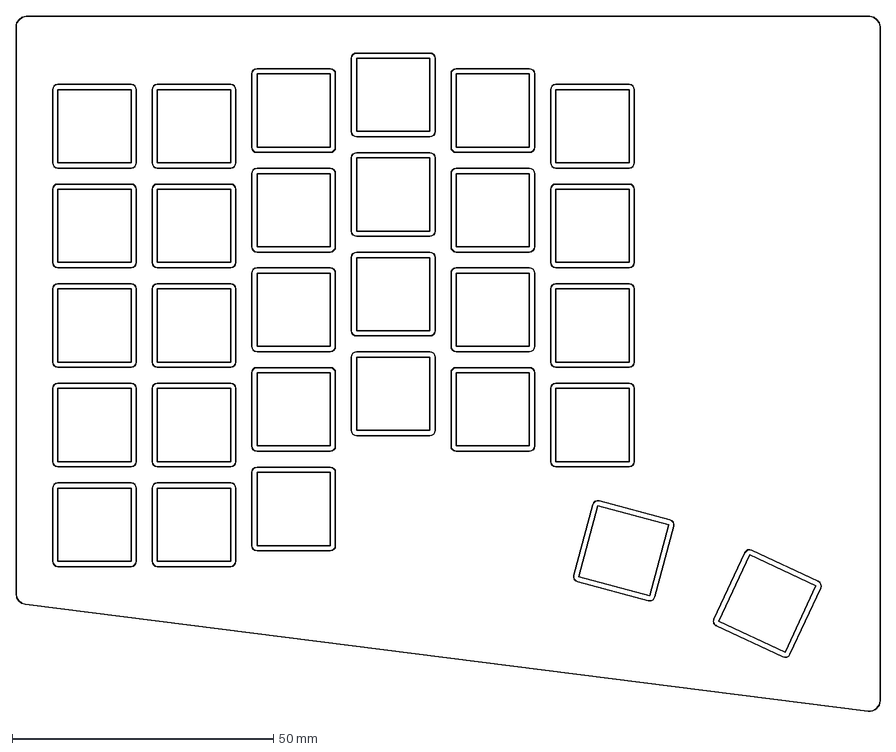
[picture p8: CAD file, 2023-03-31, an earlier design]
v0/OnShape/left.dxf
165.2 x 132.9 mm

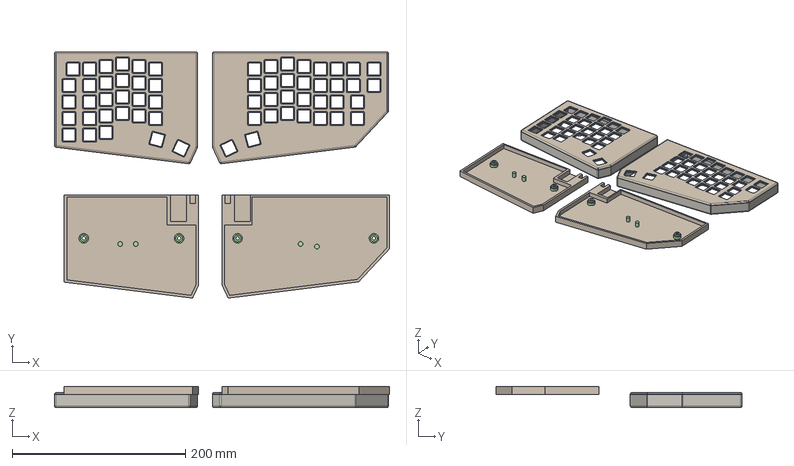
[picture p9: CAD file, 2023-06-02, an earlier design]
v1/onshape/Splinter keyboard v1.step
387.1 x 284.6 x 24.5 mm

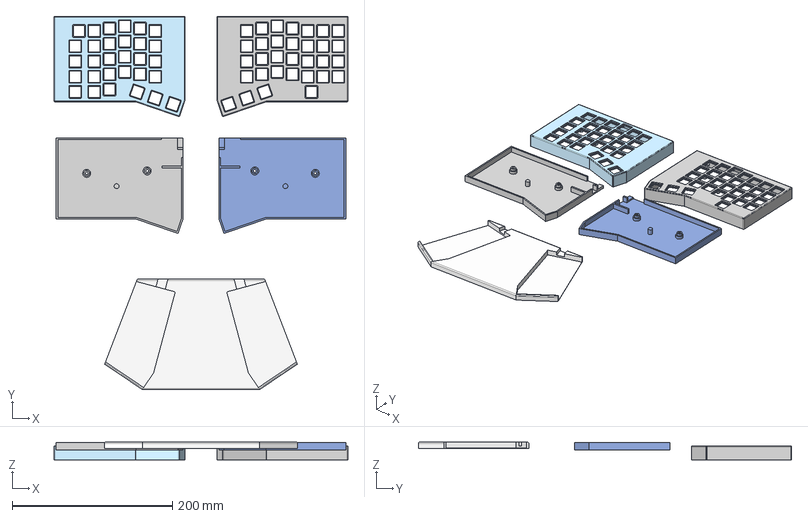
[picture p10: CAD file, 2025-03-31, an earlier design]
v2/onshape/Splinter keyboard v2.step
367.4 x 466.5 x 22.0 mm

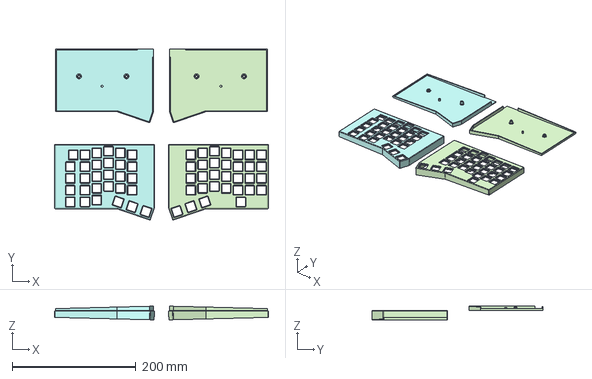
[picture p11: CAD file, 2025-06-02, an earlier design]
v3/onshape/Splinter keyboard v3.step
346.4 x 276.8 x 22.2 mm

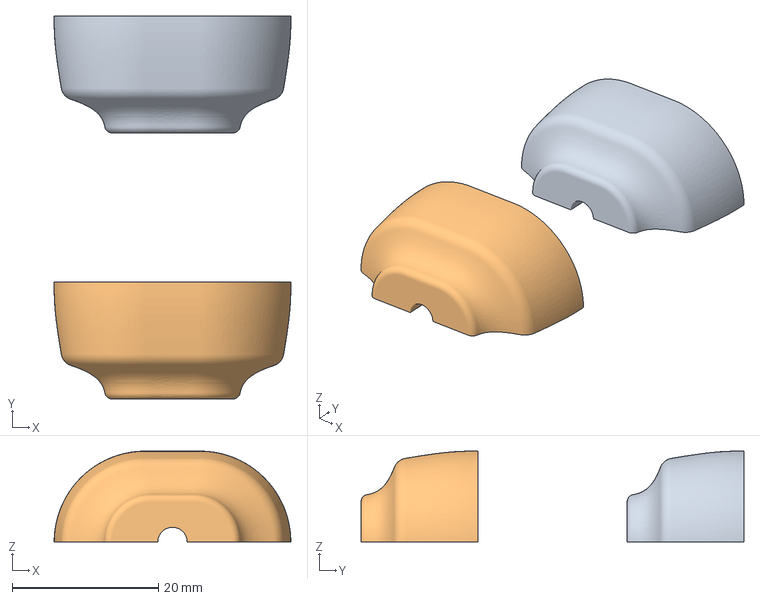
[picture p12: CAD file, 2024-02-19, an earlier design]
v3/orcaslicer/project.3mf
32.4 x 52.4 x 12.4 mm
Jewelry box feet.step x 2

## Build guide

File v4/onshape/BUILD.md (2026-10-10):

# v4 case build sheet

Feature-by-feature recipe for modelling the case in Onshape. Design rationale is in
[README.md](./README.md); this file is the numbers.

**The Onshape document is the master, modelled by hand from this sheet.** `gen-case.py`
builds the same design from the same numbers and is the validator: every difference between
the two is decided, as set out in [Validating your model](#validating-your-model).

Every position is a **dimension, not a reference**. A re-import replaces the imported
entities, so anything projected off them loses its reference while a typed value does not.
The exceptions are the switch cutouts and the boss circles, which are cut from the import
itself so they track the board.

## Target board

The case is for the assembled board stamped `config=b05d803d9317 commit=51522ad clean=yes`.
`main` carries the same `Edge.Cuts` and the same footprint placements on both halves: the
later config changes only add the un-filleted DXF export, and the later board changes are
copper. **Generate the DXF from `main`**, since 51522ad predates `full_unfilleted.dxf`.

A config change that moves the outline, a switch, a screw or a port makes the case stop
fitting this board. Re-check it against the board in hand before taking one.

## Terms

| Term | Means |
| --- | --- |
| **Boss** | A cylindrical pillar that takes a fastener. Three per half, hanging from the top underside down to the PCB |
| **Standoff** | The matching pillar rising from the bottom plate to the PCB underside, bored through for the screw |
| **Hull** | The un-filleted board outline, 160.000 x 119.000mm, in `full_unfilleted.dxf`. The case is modelled to this, not to the fabricated edge |
| **Recess** | The 16mm opening at the top face each switch nests into, so the surrounding wall covers its lower body |
| **Plate** | The bottom plate, always. The shell's top face is what the switches clip into, but it is never called a plate here |
| **Setup** | One fixturing of the part in the mill. Every flip is another setup and another fixed fee |

## How it goes together

```text
   top face   ------------------------------   z   0.00
                    |:|            <- insert bore, top of the screw path
   recess floor ----|:|------------------      z  -1.50   switch flange bears here
   top underside ---+:+---------------+##+     z  -3.00
                    |:|            <- boss, 5.50 dia
   PCB top    ------+:+---------------+##+     z  -6.00   boss ends; SHELF underside
   PCB        #######:#################|  |    <- 3.00mm NPTH
                    |:|               |##|     z  -7.60   PLATE WALL top
                    |:|            <- standoff, 5.50 dia, 2.90 clearance hole
   plate      -----[===]--------------+##+     M2.5 flat head in its counterbore, up from below
```

The board is clamped all the way round, not only at the three screws: a **shelf** hangs
from the case's top and the plate carries a matching **wall** up to meet it. The bosses and
standoffs are the same sandwich at the three screw points.

## Topology

| Part | Contents |
| --- | --- |
| **Shell** | Top face and side walls, one piece. Switch cutouts in the top, shelf inside the walls |
| **Bottom plate** | Inset closing plate with a perimeter wall, the screw heads and the standoffs |

**The shelf goes above the board, never below it.** Which side it sits on decides whether
it can be made at all. A shelf the board is pressed UP against narrows the opening going
up, which a mill reaches from below without trouble. A lip the board RESTS DOWN on would
put the full-width board pocket above a narrower lip, which is an undercut no setup
reaches, and it blocks a printed part equally since the board also goes in from below.

**The plate is inset**, finishing flush with the shell rim, so its outline is the cavity
outline less a fit clearance rather than the shell's outer profile. Deriving it from the
cavity rather than from the hull is what makes its corners match the pocket it drops into.
It consumes 1.50mm of cavity depth. No rebate is needed: the cavity is a straight extrusion
and the screws hold the plate against the stack above it. A rebate would be legal, being
wider at the open face, but it would thin the wall at the rim for nothing.

**Undercut, precisely.** Cutting from below, a feature may narrow going up but never
widen. So a chamfer or rebate at the rim is fine, and a lip under the board pocket is not.

## Machining setups

| Part  | Setup | From | Features |
| ----- | ----- | --- | --- |
| Shell | 1 | below | Outer profile, cavity, bosses, boss holes |
| Shell | 2 | above | The 16mm switch recesses, the top edge bezel |
| Shell | 3 | the top edge (+y face) | TRRS and USB openings |
| Plate | 1 | inner face | Profile, standoffs, screw holes, relief pocket |
| Plate | 2 | outer face | Counterbores, bumper recesses |

**Setup 3 is not optional.** Both ports are holes through a vertical wall, and a 3-axis
mill reaches those from neither above nor below. A right-angle head folds it back into
setup 1 if the shop has one; otherwise it is a third fixturing. Both ports sit on the same
face, so one setup covers both.

The plate's two setups are inherent to it having features on both faces.

The nested switch cutout is inherently wider at the top, so nothing reaches it from below.
The 14.5mm holes are through-features and can be cut in setup 1 or 2. Flattening the top
to a single 14.5mm hole would drop setup 2, at the cost of the switch sitting proud on a
flat face.

**Quote both variants before deciding.** The recesses are ~10-25 minutes of spindle time,
so the adder is dominated by the fixed cost of re-fixturing, and a shop may plan the op
regardless. Hollowing the block likely dominates the part cost either way. If the delta is
large, flatten the top for the aluminium variant only and keep the nesting on the print.

## Decisions this sheet assumes

| Decision | Assumed |
| --- | --- |
| Process | Print first, then aluminium; the printed half confirms fitment |
| Print orientation | Shell top-face-down; walls and bosses rise from a flat first layer, no supports |
| Wall thickness | 3.0mm |
| Top thickness | 3.0mm, recessed to 1.5mm at each switch |
| Cavity internal fillet | 2.0mm nominal, **3.20mm absolute maximum** |
| Board pocket clearance | 0.50mm per side on the hull |

**The pocket clearance is a print number, not a machining fit.** An FDM part loses 0.2 to
0.3% to XY shrink across 160mm and another 0.1 to 0.2 per wall to perimeter
over-extrusion, which closes a tenth-millimetre pocket outright and leaves a board that
will not go in. 0.50 survives that and costs the milled variant nothing, because the board
is located by its screws rather than by the pocket either way.

**The cavity fillet is a maximum, not a minimum.** It is an internal corner, so the tool
leaves material _inside_ the pocket, and that material has to miss the board's own 1.5mm
exterior fillet. Do not let a shop substitute a larger end mill.

| Cavity fillet | Clearance to the fabricated board at a 90 deg pocket corner |
| --- | --- |
| 1.50 | +0.707 |
| 2.00 | +0.500 |
| 2.35 | +0.355 |
| 3.20 | +0.003 |
| 3.50 | -0.121 |

At 2.00 the pocket's corner arc comes out **concentric** with the board's own 1.5mm fillet,
both centred 1.50 in from the sharp hull corner, so at a 90 deg corner the clearance is the
tool radius less the board fillet uniformly around the arc rather than only at its tightest
point. That is 0.500, the same as the straight edges, and no corner is tighter than an edge.

## Frame

Outline centre at the origin, +x toward the inner (thick) edge, +y up, z=0 at the shell's
top face, +z up.

Positions read off the KiCad board are in the _filleted_ frame and gain **+0.205mm in y**
to convert, since the fillet shortens the board 0.410mm and moves its bbox centre half of
that. Every value here is already converted.

| | Value |
| --- | --- |
| Hull, per half | 160.000 x 119.000 |
| `Edge.Cuts`, as fabricated | 160.000 x 118.590 |
| Top edge / bottom edge | y +59.500 / -59.500 |
| Side edges | x +-80.000 |

The 1.5mm wall fillet rounds the corners, so the fabricated height drops while the width
holds at the straight side edges. The case is modelled to the hull, never to that edge.

## Z stack

| Level | z |
| --- | --- |
| Shell top face | 0.00 |
| Recess floor; switch flange bears here | -1.50  |
| Top underside; 1.50mm switch plate above | -3.00  |
| PCB top face; boss ends here | -6.00  |
| PCB bottom face | -7.60  |
| Bottom plate top face, inner edge | -14.50 |
| Shell bottom rim / plate underside, inner edge | -16.00 |

**Specify the two edge heights, not the angle: 16.00mm inner, 12.00mm outer.** Over the
167.00mm shell that is 1.3721 deg, but the angle is derived. If the wall thickness
changes, the case width changes with it and the angle follows while the heights stay put.

The bottom slopes, so the last two rows are at the inner edge; at the outer edge the rim
is at -12.00. Usable cavity below the PCB runs **6.82mm at the inner edge to 2.98mm at the
outer**, measured at the board edges rather than the shell's.

**What the taper costs.** 1.3721 deg is not a working tent angle, so the slope is there for
the look, and it buys that at the price of three standoff heights, two screw lengths, and
putting the tightest clearance in the design on the shallow side. A flat 15.50mm case would
give the Liatris +1.00, the jack +1.20 and the socket +4.55 with one standoff height and
one screw length. Recorded so the trade is visible, not as a proposal.

## Parameters

| Parameter | Value | Source |
| --- | --- | --- |
| Wall thickness | 3.00 | decision |
| Top thickness | 3.00 | decision |
| Switch recess depth | 1.50 | nesting |
| Plate at a switch cutout | 1.50 | MX standard, 1.5mm +-0.1mm |
| Bottom plate | 1.50 | takes the flat head's full height |
| Board pocket | 161.00 x 120.00 | hull + 0.50/side; the board itself is 0.705/side loose in y |
| Shell outer profile | 167.00 x 126.00 | pocket + wall |
| Boss and standoff diameter | 5.50 | = 2 x `screw_boss_radius`, the DXF's own circle |
| Boss height | 3.00 | top underside to PCB |
| Material above the PCB at a boss | 6.00 | top 3.00 + boss 3.00; **4.50 where a recess overlaps** |
| Insert hole, printed | 3.60 dia | M2.5 melt diameter; depth is per boss, see below |
| Tapped hole, machined | 2.05 tap drill, M2.5x0.45 | same per-boss depths |
| Screw | M2.5 button head, ISO 7380 | head 4.70 dia x 1.50, **flat underside**; two lengths, see below |
| Screw clearance hole | 2.90 dia | through the plate and the standoff |
| Counterbore in the plate | 5.00 dia x 1.50 deep, **flat bottomed** | head + 0.30; floor is the standoff base |
| Perimeter shelf, on the shell | 2.00 wide, underside at -6.00 | measured in from the cavity, so it laps the board by 1.50, inside its 2.00 keepout ring |
| Perimeter wall, on the plate | 2.00 wide, top at -7.60 | meets the shelf through the board, lapping it by 1.65 |
| Wall relief | none inward of x +-50.00 above y +45.00 | the MCU, the jack and both ports are there |
| Flared standoff base | 8.00 dia, up to -9.75 | = the built v4 lid; gives the counterbore a 1.50 annulus |
| Switch cutout / recess | 14.50 / 16.00, R1.00 corners | see below |
| Top outer edge bezel | 1.00 x 45 deg | one chamfer pass; the switch recesses stay square |

**The wall stops short of the top-inner corner.** Everything hanging below the board is
there, the MCU and the jack, and so are both ports. A wall running the full perimeter sits
on the jack's body and blocks both plugs.

**The standoff needs a flared base.** The counterbore runs the plate's full thickness, so
without a flare a 5.00 bore inside a 5.50 standoff joins the two by a 0.25mm annulus, 4.12
mm2 per boss: the head bears on the standoff and the plate hangs off that ring, which on an
FDM part is under one extrusion width. Flaring the base to 8.00 makes it 1.50mm and 30.63
mm2, seven times the area. The built v4 lid uses 8.00 as well.

**Height is what constrains a flare, not diameter.** It stops under the hotswap sockets
hanging 1.85 below the board, and every pad it would otherwise have to dodge is above it,
so the 2.04mm inner-pinky pad clearance that caps the standoff does not cap this. Stopping
at -9.75 leaves 0.30 to the sockets. Do not let it reach them: that clearance is the only
thing between the flare and a part.

**The 14.50 cutout is not slack.** An internal corner rounds _into_ the void, so an R1.00
corner cut into a 14.00 hole would bind a switch by 0.207mm. At 14.50 it clears by 0.146mm
against a 14.00 section with 0.5mm corner radii. The switch is located by the 16.00 recess,
not by this hole.

### Screw bosses

Left half, from the outline centre. The right half is the exact mirror (negate x).

| Boss | Position | Standoff height | Standoff + PCB | Bore depth | Screw | Engagement |
| --- | --- | --- | --- | --- | --- | --- |
| Outer pinky | (-42.375, -3.650) | 3.88 | 5.48 | 5.00 | M2.5x10 | 4.52 |
| Inner pinky | (33.825, 0.050) | 5.71 | 7.31 | **4.00** | M2.5x11 | 3.69 |
| Centre | (-3.325, 22.175)  | 4.82 | 6.42 | **4.00** | M2.5x10 | 3.58 |

**The plate is not in the stack.** A flat-underside head bears on the counterbore floor,
which is the standoff's base, and its length is measured from there. A countersunk head
would have added the plate's 1.50 to every row and needed a longer screw.

**Any flat-underside head works; the counterbore diameter is what follows from the choice.**
5.00 suits a 4.70 head (button ISO 7380, socket cap DIN 912) with 0.30 to spare, and leaves
0.25 of standoff outside it. A 5.00 pan head needs 5.30, which leaves 0.10 and a knife edge
on the standoff, so grow the standoff if you go that way. Head height decides flushness
only: 1.50 finishes level with the plate, 1.70 stands 0.20 proud, and neither affects the
screw length, since that is measured under the head.

The outer pair sits 3.70mm apart in y. That is forced: the pinky columns are asymmetric,
so the two screws cannot share a y while clearing both switch holes and pads. Do not level
them.

**Two bosses take a 4.00 bore, not 5.00.** A 16.00 switch recess overlaps the inner-pinky
and centre bosses, so the material above them is 1.50 (top left over the recess) + 3.00
(boss) = 4.50, not 6.00. A 5.00 bore breaks out into the recess floor:

| Boss | Recess edge from the boss axis | 1.80 bore radius | Breakout |
| --- | --- | --- | --- |
| Inner pinky | 1.745 | 1.80 | 0.88 x 0.06mm |
| Centre | 1.695 | 1.80 | 1.21 x 0.11mm |

The placement rule holds the boss clear of the 14.50 **hole** (tangent on both halves at
these two), which is what stops the boss fouling the switch body. It says nothing about the
16.00 **recess** above, which is what the bore has to miss.

**The bosses mirror; the key field they sit in does not.** On the right half a recess also
clips the outer-pinky boss, putting its recess edge 2.25mm from the bore axis against a
1.80 bore radius. That is 0.45mm of wall over the bore's top 0.50mm, where the left half
has 1.12mm. No breakout either way, so the 5.00 bore stands, but do not read the table's
"exact mirror" as covering what surrounds them, and see the printed-insert risk below.

`gen-case.py` hard-errors on a bore that reaches the recess band without clearing the
recess wall, so this table cannot go stale against the key field. Readback cannot cover
it: a breakout trims the bore's face without splitting it or changing its height, so the
depth check and the face census both pass a shell that has one.

**The standoffs are three different heights** because the plate is sloped, so the three
screws see stacks from 5.48 to 7.31mm. Two lengths cover it, as tabulated: every screw
takes at least 3.00mm of thread and none bottoms in its bore. Do not try to absorb the
spread in the counterbore: it is 1.50 deep and the head is 1.50 tall, so there is no depth
to give.

**Clearance to the nearest side-B pad**: 3.54mm outer pinky, **2.04mm inner pinky**,
3.98mm centre. Those are measured to the pads, and the Kailh socket body is larger than
its lands, so the real gap at the inner pinky is smaller by an unknown amount. That is why
the standoff is 5.50 and not larger.

### Ports, on the top edge

| Feature | Position |
| --- | --- |
| USB-C notch, already in the outline | x +56.663 .. +66.663, cut 7.271mm down from y +59.500 |
| TRRS jack centre | (74.650, 59.500) |

**Both parts mount on side B, so both openings sit entirely below the PCB.** Neither is
anywhere near the z=-6.00 board plane, which is the mistake to avoid.

| Opening | Size | Centre z | Source |
| --- | --- | --- | --- |
| TRRS, round | 5.50 dia | **-10.50** | measured off the built v4 case |
| USB-C, through the wall | 9.50 w x 4.00 h | **-10.25** | measured on a printed part of this design; width is stated, see below |

**The heights are measured, never derived.** The built v4 case shares this z stack exactly
(top face 0, top underside -3.00, PCB -6.00 to -7.60), so its port centres transfer
directly, and the TRRS is taken straight from it. The USB sits 0.50 higher than that case
carries: the inherited height printed low on this design. Re-measure on hardware before
changing either, and treat the TRRS as due for the same check, since it comes from the same
source as the height that moved.

Add 0.3-0.4mm printed, 0.2-0.3mm machined. **Both are plain cutouts straight through the
wall.** No counterbore and no recess: a pocket on the outer face reads as the port being
sunk into the case rather than opened through it.

The cost is cable boots. The connector sits back from the case face and a USB-C plug shell
is only about 6.5mm long, so a cable with a fat overmold may bottom on the outer face
before it seats. Settle it on the printed half with the cables you actually own; a
13.00 x 7.00 x 1.50 counterbore on the outer face is the fix if one of them will not go.

**Why 9.50 wide, and why it is stated rather than derived.** It sits inside the board's own
10.00 notch, so the plug clears the board edge, and it clears an 8.34mm plug shell by 0.58
per side. How far inside the notch it has to sit is set by how far the board can move,
which is the screws and not the pocket: a 2.5mm screw in a 3.00mm hole is 0.25 per side
whatever the pocket fit is. Deriving the width from the pocket clearance would shrink the
port every time the pocket was loosened, which is the wrong direction.

Wall left below each opening: 2.54mm at the TRRS, 3.23mm at the USB. The TRRS is thin
enough that a printed shell wants an extra perimeter there.

**Nothing in the case follows the board's USB notch.** Not the outer profile, not the
cavity, not the plate. That notch clears the plug's overmold, which sits below the board
entirely, so to the case it is only a bite out of an edge that should run straight.
Inheriting it puts a jog in all three outlines and leaves a pointless tongue of material in
the pocket. Fill it in the hull before offsetting any of them. The result is a void where
the board is absent, which costs nothing and gives the plug more room rather than less: the
top edge is straight and both ports are simply openings in the back wall.

## Measure the built board first

Several figures below the board come from memory or from the previous case. With the
board in hand, measure these before modelling. Where a measurement differs, change the
parameter here and in `gen-case.py`, then re-run it so its guards see the new value.

| Measure, on the assembled board | Sheet assumes | Decides |
| --- | --- | --- |
| Board thickness | 1.60 | every z below the board; whether the plate sits flush |
| Board underside to the lowest point of the installed MCU | 5.40 | the binding margin; see "MCU seating" under Open risks |
| Board underside to the bottom of a hotswap socket | 1.85 | where the standoff flare stops (z -9.75) |
| Board underside to the bottom of the TRRS jack body | 5.20 | jack margin |
| Board underside to the USB-C receptacle centre | 2.65 | USB opening centre, z -10.25 |
| Board underside to the TRRS bore centre | 2.90 | TRRS opening centre, z -10.50 |
| Board top to the plate-bearing shoulder of a seated switch | 4.50 | recess depth; see "Switch seating" under Open risks |
| Kailh socket body edge to the right half's inner-pinky screw hole | lands only | whether the 5.50 standoff and 8.00 flare clear the body |
| Switch top housing width | 15.60 | the 16.00 recess fit |
| Plug shell width, and overmold size of the cables you will use | 8.34 | USB opening width; whether the outer-face counterbore is needed |

A port centre measured from the board underside sets the opening's z as -7.60 less that
figure (on a 1.60 board). That is a measurement off this board, which is what "measured,
never derived" asks for.

## Modelling in Onshape

**Put every Parameters row in a Variable feature** at the top of the tree and type
`#name` into features, never the number. A number typed into a feature is a second copy,
and the sheet changes.

**Three Part Studios**: "Body" builds shell and plate up to, but not including, the switch
features. "Left" and "Right" each bring in Body with a Derived feature, "Right" mirrors it
about the Right plane, and each then cuts its own switch recesses and cutouts from its own
half of the DXF. The body mirrors exactly; the key field does not (see Right half).

Traps, each geometric rather than specific to `gen-case.py`, so they apply in Onshape too:

- **Fill the USB notch in the hull before any offset.** Every loop below is offset from the
  notch-filled hull. See Ports for why nothing follows the notch.
- **Offset each loop from the hull, never from another offset loop.** The cavity loop's
  corners are R2.00. Offsetting it inward 2.00 for the shelf collapses those arcs to zero
  radius and the feature fails. The shelf's inner loop is the hull inset 1.50 and the plate
  wall's is the hull inset 1.65, each with its own corners rounded at R2.00.
- **The one exception is the plate outline**, which is the finished cavity loop inset 0.15,
  so its R1.85 corners match the pocket it drops into.
- **Round only the cavity's internal corners.** The hull has five convex corners and one
  re-entrant one. A tool rounds the five at its radius and leaves the re-entrant corner
  sharp, so fillet the five and leave the sixth alone.
- **One construction plane for the slope**, through z -16.00 at the inner shell edge and
  z -12.00 at the outer (x +83.50 and -83.50 on the left half). The shell's bottom cut,
  both plate faces (that plane and a 1.50 offset) and every standoff's lower end reference
  it.
- **Sketch plate holes on a horizontal plane.** Onshape's Hole feature drills normal to its
  sketch plane, so a hole sketched on the sloped plate face comes out tilted 1.37 deg and
  its counterbore floor is no longer square to the screw. The relief pocket and bumper
  recesses are the opposite: sketch them on the plate's own faces so their floors run
  parallel to it.
- **Extend port cuts past both wall faces.** A cut ending exactly on a face leaves
  coincident faces and a non-manifold solid.
- **Cut switch features straight from the imported curves**, not redrawn. They carry the
  corner fillets the cutout width depends on.

## Validating your model

Export one half from Onshape as STEP, shell and plate assembled (plate in place, not
exploded), in millimetres and in the sheet's [Frame](#frame). One file holding both parts
or one file per part both work. Put exports under `dist/v4/onshape/`, which is not
committed. Then:

```bash
FC_HALF=left FC_COMPARE=dist/v4/onshape/onshape-left.step \
  freecadcmd v4/onshape/gen-case.py
```

It builds the reference half, Boolean-subtracts each way, and reports every region where
the two disagree: `extra` is material in your model the reference lacks, `missing` the
reverse, each with its volume, centre and size in the sheet's frame. It exits nonzero on
any region not on record. A part whose centre is over 1mm from the reference's stops it
before comparing, since every face would differ and the cause is the export frame.

**Decide every region one of three ways.**

| Decision | When | Then |
| --- | --- | --- |
| Move to the reference  | your model departs from the sheet, and the sheet's version is right | change your model; nothing is recorded |
| Intentional difference | a deliberate departure in something the sheet does not model | add the entry the report prints to `differences.json`, with a reason |
| Error | either side is wrong against the sheet or the board | fix the side that is wrong; nothing is recorded |

**A deliberate change to a sheet dimension is not an intentional difference.** Change it
in this sheet and in `gen-case.py`, and the region goes away. Recording it instead leaves
the sheet describing a case nobody is building. Intentional is for what the sheet does not
model: a cosmetic feature, an extra fillet, a fit opened up on a printed coupon.

**An intentional difference is outside the script's guards.** The bore-breakout,
bumper-over-relief and relief-under-wall checks run on the reference only, so a recorded
region that touches one of those features needs its [Verify](#verify) row checked by hand.

An error on the script's side goes into `gen-case.py`, and into this sheet too if the
number was wrong here.

**`differences.json`** holds one entry per intentional difference:

```json
{ "half": "left", "part": "shell", "kind": "extra", "box": [x0, y0, z0, x1, y1, z1], "reason": "..." }
```

A region is accepted when its bounding box lies inside an entry's `box`. For each
unrecorded region the report prints a ready entry, its box rounded outward to 0.1mm, with
an empty `reason` to fill in. An entry that matches no region fails as stale: the
difference is gone, so delete it. Each half is recorded separately, since the key fields
differ.

## Part A: shell

1. **Sketch "Outline (imported)"**, Top plane. Insert
   `dist/v4/ergogen/outlines/full_unfilleted.dxf` in millimetres. Constrain the left half's
   outline centre to the origin. **Never draw in this sketch**; re-importing is the only
   edit it should take.
2. **Sketch "Hull"**, the left-half outline with the USB notch closed by a straight line
   along the top edge. Every offset below starts from this loop.
3. **Extrude "Shell body"**, Hull offset outward **3.50mm** (clearance + wall), from z 0
   down past z -16.00, then cut away everything below the slope plane. The bottom rim lands
   at **-16.00 at the inner edge and -12.00 at the outer**.
4. **Extrude cut "Cavity"**, Hull offset outward **0.50mm**, from **z -3.00** down through
   the open bottom. Fillet its five internal vertical corners at **2.0mm, 3.20mm maximum**.
5. **Extrude "Shelf"**, the ring between the cavity loop and Hull inset **1.50mm** (corners
   R2.00), from **z -3.00 down to -6.00**. The board is pressed up against its underside.
6. **Bosses**, on the top underside: three circles r **2.75** at the positions above,
   extruded down **3.00mm** to the PCB top face.
7. **Boss holes**, from each boss's lower face upward, 3.60 dia (or the 2.05 tap drill),
   **to the per-boss depth in the boss table**: 5.00 outer pinky, 4.00 the other two.
8. **Port openings** cut straight through the side wall, overshooting both faces.
9. **Bezel**, 1.00 x 45 deg on the top face's outer edge only.

In the Left and Right studios, after the Derived (and, on the right, the Mirror):

1. **Extrude cut "Switch recesses"**, the 16.0mm curves from the import, top face down to
   **z -1.50**.
2. **Extrude cut "Switch cutouts"**, the 14.5mm curves from the import, through the
   remaining 1.50mm. Cut both sets **as imported**. The recess openings get no bezel:
   the nesting look depends on the switch meeting a crisp edge.

## Part B: bottom plate

1. **Extrude**, the cavity loop (with its R2.00 corners) inset **0.15mm**, **1.50mm**
   thick, between the slope plane and its 1.50 offset, flush with the rim.
2. **Perimeter wall**, the ring between the plate outline and Hull inset **1.65mm**
   (corners R2.00), from the plate's top face up to **z -7.60**. Remove it over
   **x > +50.00 and y > +45.00**, the top-inner corner.
3. **Standoffs**, r **2.75** at the three boss positions, rising to the PCB underside at
   z -7.60. Heights are in the boss table. Each sits on a flared base, r **4.00**, from
   the plate up to **z -9.75**.
4. **Screw holes**, 2.90 dia, through the plate and up the full height of each standoff
   to z -7.60, so the screw passes through the standoff and the PCB into the boss's
   insert. Each has a flat-bottomed 5.00 counterbore through the plate's full 1.50mm,
   sketched on a horizontal plane. The counterbore's floor is the flare's base, so the
   standoff keeps its height.
5. **Relief pocket**, on the inner face, **0.75mm deep**, one plain rectangle over
   x **+50.25 .. +77.60**, y **+23.35 .. +58.60**. Leaves 0.75mm of plate.
6. **Bumper recesses**, 8.00 dia x 0.50 deep on the outer face at (-70, +50), (+45, +50),
   (-70, -32), (+65, -50). Floor **parallel to the plate faces**, so the depth is 0.50 and
   the plate left is 1.00 right across every foot. All are well clear of the three screw
   heads.

**Only the screw counterbore has a horizontal floor.** The plate is a parallel-sided slab
lying at 1.3721 deg, so "flat" and "level" are different instructions here and each feature
has to say which it means. The counterbore means level: the screw axis is vertical and a
flat head seats square to its own axis, so its floor is horizontal and its depth below the
outer face therefore varies 1.447 to 1.553 across its width. Every other feature means
parallel to the faces. A bumper recess cut level instead would run 0.417 to 0.585 deep and
leave 1.084 to 0.916 of plate, different at each edge of every foot.

**Keep every bumper out of the relief pocket.** The two cut opposite faces, so an overlap
leaves 0.25mm of plate, and leaves it directly under the parts the relief is there for.
Nothing fits between the pocket and the plate edge in the top-inner corner, which is why
the top-edge bumper sits at x +45.00 rather than out at +70.00 with its opposite number.
`gen-case.py` hard-errors on an overlap; readback cannot see one, since both features are
present, the right size, at the right depth, and the plate is still one closed solid.

**The relief pocket is not optional on an aluminium plate.** The MCU stack has +0.77mm of
nominal clearance and +0.03mm if the module bottoms out in its sockets, and the plate would
be a conductor that close to exposed pin tails. The pocket takes the worst case to +1.52mm
and costs nothing to machine in the same setup.

**One rectangle, covering the Liatris and the jack together**, rather than a pocket each
with an island between them: it is meant to be lined with tape, and a plain rectangle takes
a strip.

**The margin around the parts is one-sided, and has to be.** Inward the pocket runs over
bare board and carries 2.58 in x and 3.00 in y, comfortably past the 0.71 the pocket allows
in y, which is the widest the board can sit off centre at any point in assembly, so a part
cannot end up standing over full-thickness plate. Outward there is nowhere to buffer into,
because both parts run out to the board's own top edge and the plate ends 0.35 past it.
Every limit here is set by the plate, not by the parts:

| Edge | Limit | Set by |
| --- | --- | --- |
| x +50.25 | 2.58 clear of the Liatris | the top perimeter wall survives inboard of x +50.00, and a pocket at its foot would undercut it |
| y +23.35 | 3.00 clear of the Liatris | free; nothing is near |
| x +77.60 | 0.18 short of the jack body  | the perimeter wall runs at 78.35 below y 45, same undercut |
| y +58.60 | 0.90 short of the board edge | a 1.25 rim at the plate edge |

**The wall is what bounds the pocket on three sides.** It is half the board's clamp and it
stands on the plate's full thickness, so a pocket reaching its foot thins the root. That
undercut is invisible to a solid intersection test, since the wall rises from the plate's
top face while the pocket cuts down from it and the two touch without sharing volume;
`gen-case.py` tests the footprints instead, and hard-errors.

**Neither shortfall is a clearance problem.** Under the uncovered sliver of jack body the
plate is still 1.42 away, and under the uncovered top strip the Liatris is 3.76 away, its
pin tails having ended well below at y 56.54. Both are larger than the 0.75 the pocket
would add. Widening either means thinning the rim or stepping the pocket, which buys
fractions of a millimetre where there are already millimetres.

The MCU's reset and boot buttons and the board's own reset switch all face the plate;
access is by removing it, so no holes are needed.

**No support posts.** A post short enough not to lift the board off its bosses is too short
to carry anything, and typing load reaches the shell through the switch flange rather than
the PCB. The plate is unloaded.

## Right half

Mirror both parts: the outline mirrors exactly and the only half-specific geometry is the
switch cutouts. Cut those from the **right half of the DXF**, not from a mirrored copy of
the left's. The halves carry 30 and 32 switch cutouts and 14 positions have no mirrored
counterpart, so a mirrored key field is the wrong key field.

## Assembly

**Switches go into the shell first, then the board goes on.** A 15.6mm top housing cannot
pass a 14.5mm hole from below, so there is no other order: clip all 30 (or 32) switches
into the shell's top face from the outside, then bring the board up into the cavity onto
every socket at once.

The cavity is a straight bore, so the board cannot be rocked in the way a bare
plate-and-switch assembly usually is. Seat it evenly, thumb cluster last, until it meets
the shelf all the way round. Then the plate goes on and its wall closes the sandwich.

**If the sockets fight the pins, fit the plate first and let the screws press the board
home.** The plate's perimeter wall and its three standoffs all top out at -7.60, the board's
underside, and the screws draw the plate up toward the shell, so the wall bears on the
board right around its edge and pushes it onto every pin at once while the screws hold it
to 0.25 per side. That is tighter than the pocket and it spreads the seating load over the
whole perimeter rather than through the three bosses. Draw the three evenly, a turn at a
time, so the board goes up flat.

**Nothing datums the board.** The 5.50 boss butts its top face and never enters the 3.00mm
hole, and a boss cannot pilot into that hole because the 3.60 insert bore is wider than the
hole itself. **Which constraint registers it depends on whether the screws are in.** Press
the board on by hand and only the pocket is holding it; fit the plate and draw the screws
and they take over at 0.25, which is tighter.

| Constraint | Play, per side | In force |
| --- | --- | --- |
| Pocket in x | 0.50 | whenever the screws are not |
| Pocket in y | 0.705 (the fillet takes 0.410 off the board height, the pocket is cut to the hull) | whenever the screws are not |
| Screw in its 3.00 hole | 0.25 | once the plate is on, including while it presses the board home |
| Switch in its 16.00 recess | 0.20 | always |

So a socket seated by hand can sit **0.54mm** off its switch pins in x and **0.73mm** in y,
root sum square against the switch's own play, and 0.70 / 0.91 worst case. Seated on the
screws it is **0.32mm**, whatever the pocket is cut to. That is the reason to reach for the
plate rather than for a tighter pocket if the sockets fight: the pocket has to stay loose
enough that a printed shell accepts the board at all.

**A printed shell and a milled one part company on the hand-seated figures**, and the
pocket clearance is what splits them. A printed pocket comes out undersize, which is the
whole reason the clearance is 0.50, so its effective play lands near half those numbers. A
milled pocket is 0.50 true. The screw-seated figure is the same for both.

## Printing

Top face down. The first layer is the top face with its 16mm openings; at 1.50mm the
opening steps in to 14.5mm, a 0.75mm inward overhang per side that bridges without
support. Walls, bosses and standoffs rise from there, so nothing else overhangs.

**Expect the printed recesses to need opening up.** 16.00 on a 15.60 switch is 0.20 per
side and FDM holes come out 0.1-0.3mm under, so plan on 16.2-16.4 for the print while the
machined part keeps 16.00. Print a three-switch coupon and settle it before committing a
whole shell. The same goes for the plate's 0.15mm fit clearance.

The port openings are holes in a vertical wall, so their top edges bridge. Chamfer or
teardrop them if they sag.

## Clearances

| Item | Available | Needs | Margin |
| --- | --- | ----- | --- |
| **Liatris** | 6.17, 6.92 over the relief pocket | 5.40  | +0.77, **+1.52** with the pocket |
| Hotswap socket, right half | 3.07 | 1.85  | +1.22 |
| TRRS jack | 6.62 | 5.20  | +1.42 |

Everything tall mounts on side B, so the 3.00mm above the PCB only has to clear the
switches and the whole height question is below the board.

| Below the PCB | mm | Source |
| --- | --- | --- |
| Mill-Max 315-43-112-41-003000 socket | 2.00 - 2.41 | measured ~2.0; datasheet `.095"` |
| Liatris PCB | 1.00 | splitkb states 1mm |
| Liatris down-facing, pin stubs tallest | 2.00 | measured |
| **MCU stack** | **5.40** | measured; **binds** |
| TRRS jack body, PJ-320A | 5.20 | measured |
| Hotswap socket, Kailh CPG151101S11 | 1.85 | **unverified, from memory** |

**Evaluate any outer-edge change on the RIGHT half.** Its 1u pinky plus the `zones.extra`
inner column puts a socket land 3.68mm from the outer board edge against the left's
16.73mm, so the outer edge height bites there first.

**Span costs more than height on a sloped floor.** Read a part's clearance at its
outermost extent, not its innermost: that is where the floor has risen furthest. The MCU
is shorter than the jack but reaches 27.22mm in from the inner edge against the jack's
8.45mm, so it loses three times as much depth to the slope and is the binding part.

## Open risks

**Switch seating.** The PCB sits 4.50 below the bearing surface.

| Shoulder to PCB | Recess floor | PCB top | Source |
| --- | --- | --- | --- |
| **4.25** | -1.75 | -6.00 | the built v4 case, measured off its STEP |
| 4.50 | -1.50 | **-6.00** (used here) | this sheet's 1.50 recess on the same PCB plane |
| 5.00 | -1.50 | -6.50 | Cherry's 5mm PCB-to-plate figure, if measured to the plate top |

The built case puts its PCB plane at exactly -6.00 and -7.60, the same as here, so that
much is confirmed on hardware. What differs is the recess: it is 1.75 deep there and 1.50
here, which moves the bearing surface up 0.25 and is the whole of the 4.25-to-4.50 change.
The 1.50 recess is a deliberate choice for a 1.50mm switch plate, not a carry-over.

**Deeper is the safe direction**: too deep and the switch seats on the plate with its base
floating clear; too shallow and the base hits the PCB before the shoulder reaches the
recess floor, so the switch sits proud. 4.50 is therefore 0.25 to the safe side of a case
that works, which is the reassuring direction to be wrong in. Whether Cherry's 5mm is to
the plate's top or bottom face could not be established; the datasheet drawings are raster
images. **The built board settles it**: measure the shoulder height on a seated switch (see
Measure the built board first).

**Switch seating and MCU clearance pull against each other.** Dropping the PCB to -6.50
spends the entire MCU margin, since every millimetre the board goes down is a millimetre
off the cavity below it. If the printed half shows switches sitting proud, add 0.50mm of
case height rather than moving the board. Seating also decides where typing load goes: a
switch that seats on the recess floor puts it into the shell, and one that bottoms on the
PCB puts it into a board whose three screws all sit between y -3.65 and +22.18.

**MCU seating.** The +0.77mm assumes the module's 4.75mm pin tail passes through the
4.01mm of socket and board bore and stands proud above the main PCB. If it bottoms out the
MCU seats 0.74mm lower and the margin is +0.03mm. **The built board settles it**: 5.40 from
the main board's underside to the lowest point of the MCU means it seated.

**Hotswap socket height.** 1.85mm is from memory, not a datasheet. It has +1.22mm of
margin to the plate, so it is unlikely to bite there, but it also sets where the standoff
flare stops, which has only 0.30. Measure it on the built board.

**The right half's outer-pinky boss has a 0.45mm band of wall.** A recess clips that boss
on the right half only, over the bore's top 0.50mm. Machined, 0.45mm of aluminium beside a
tapped hole is fine. Printed, it is about one perimeter, thin enough that a slicer may drop
it and leave the bore open to the recess, which is cosmetic rather than structural.

**Seat every insert flush with the boss's lower face, not deeper.** A 4.00mm insert in the
5.00 bore then ends 0.50 short of the band, so nothing is pressed against the thin wall.
Driving one past flush is the way to blow it out. **Check it** on the right half's outer
pinky first, before doing the other five.

**The plate finishes flush by tolerance stack, not by a datum.** Its z is set by boss, PCB
and standoff, so JLCPCB's +-10% on a 1.6mm board moves it +-0.16 against the rim and it can
sit that far proud. Left alone deliberately: recessing it means shortening the standoffs,
which raises the plate and takes the same amount off the cavity below the PCB, where the
MCU margin is the tightest number in the design. The lever, if the seam bothers you, is
+0.20mm of case height rather than a shorter standoff. Bumpers carry the case either way.

## Verify

The `FC_COMPARE` run holds your model to the reference everywhere it has not been
recorded as intentional, so these rows need checking by hand only where a recorded
difference touches them:

| Check | Expected |
| --- | --- |
| Cavity loop size | 161.00 x 120.00 |
| Gap from cavity to board outline | near-constant around the perimeter |
| Board outline points outside the cavity | none |
| Boss bore depths | 5.00 outer pinky, 4.00 the other two; none breaks into a recess |
| Port opening centres | z -10.50 TRRS, -10.25 USB, both below the board |
| Top edge in plan | straight across; no notch inherited from the board |
| Plate relief pocket | present, 0.75 deep, over the whole Liatris footprint |
| Plate under each bumper | 1.00; no bumper recess inside the relief pocket |
| Relief pocket vs plate wall, in plan | no overlap; the pocket stays inside the wall's relief |
| Shelf underside / plate wall top | z -6.00 / -7.60, meeting through the board |
| Both halves' switch cutouts | each cut from its own half of the DXF, 30 left and 32 right |

A wide spread in that gap means the profile is not the outline. The bore, bumper and
relief rows are the three defects a closed, correctly sized solid can still carry, so check
them with the Measure tool rather than by eye. Then **print and assemble a half before
ordering aluminium**: the printed part settles switch seating, MCU
clearance and the port openings for a few hours of filament.

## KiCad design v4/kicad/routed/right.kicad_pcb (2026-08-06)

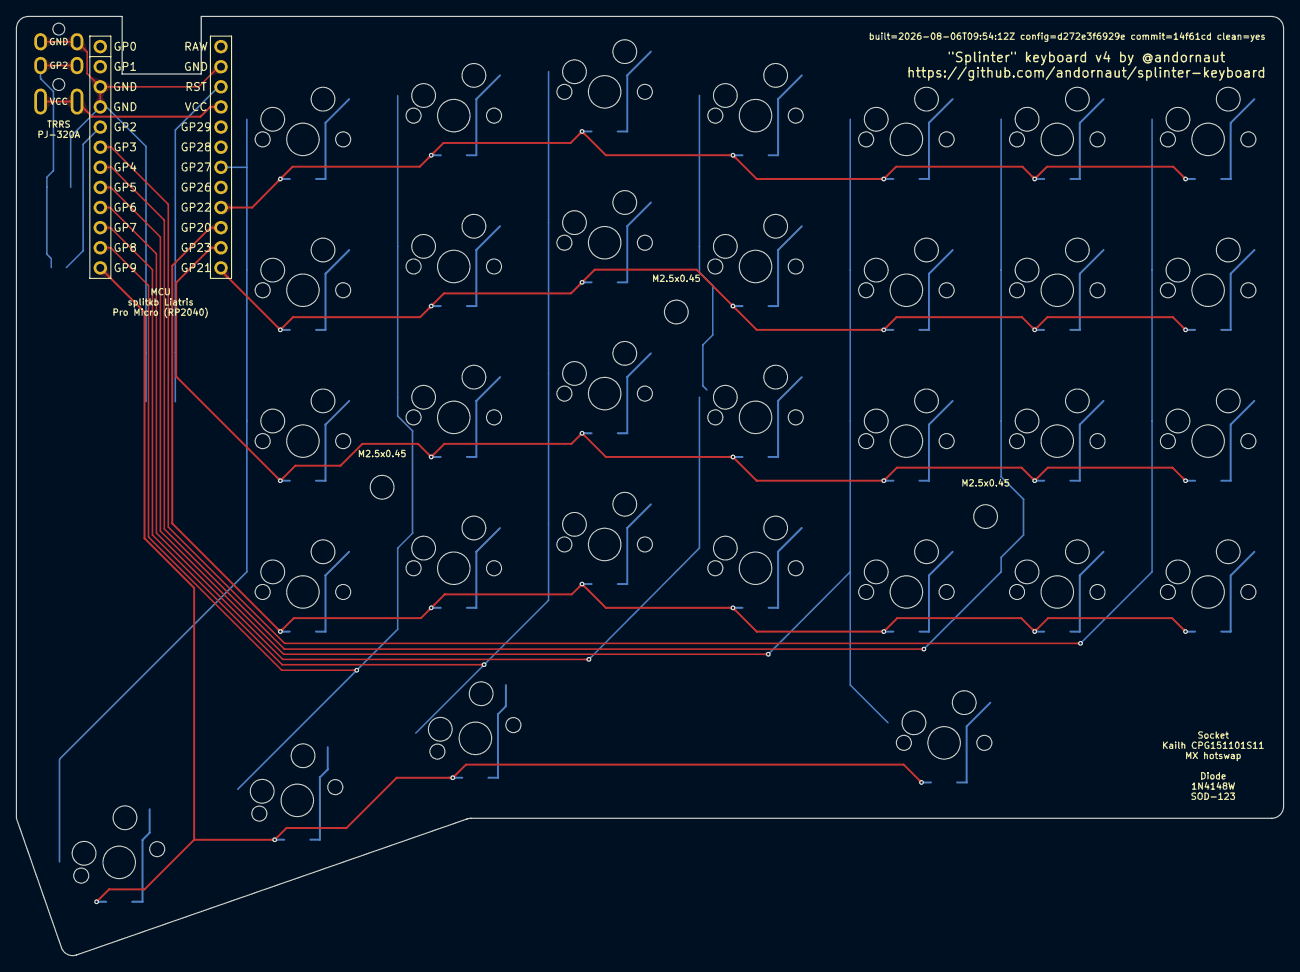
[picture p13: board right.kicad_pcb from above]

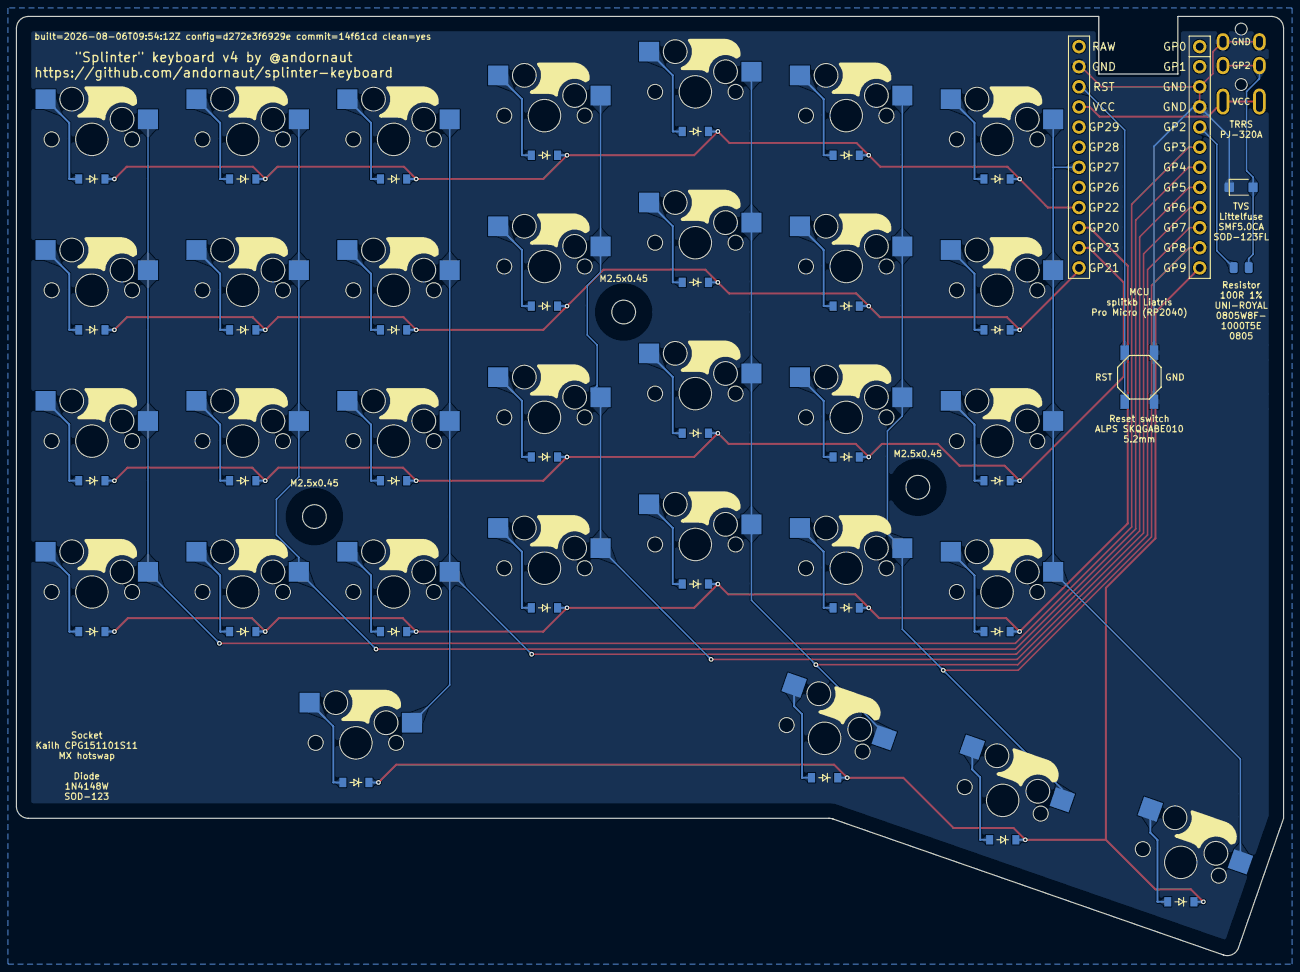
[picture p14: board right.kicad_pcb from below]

Board: 2 copper layers, 160.0 x 118.6 mm, 72 parts (68 on the bottom side), 49 nets.

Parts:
B1: SW_TACT_ALPS_SKQGABE010
D1, D2, D3, D4, D5, D6, D7, D8, D9, D10, D11, D12, D13, D14, D15, D16, D17, D18, D19, D20, D21, D22, D23, D24, D25, D26, D27, D28, D29, D30, D31, D32: diode_sod123
D33: SMF5.0CA; D_SOD-123FL
MCU1: mcu_liatris
MH1, MH2, MH3: mounting_hole_npth
R1: 100R; R_0805
S1, S2, S3, S4, S5, S6, S7, S8, S9, S10, S11, S12, S13, S14, S15, S16, S17, S18, S19, S20, S21, S22, S23, S24, S25, S26, S27, S28, S29, S30, S31, S32: switch_mx
TRRS1: trrs_pj320a (reversible, symmetric)

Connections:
DATA_RAW: D33.A, R1.1, TRRS1.3
GND: B1.1, D33.K, MCU1.2, MCU1.21, MCU1.22, TRRS1.2
P2: MCU1.20, R1.2
P3: MCU1.19, S26.1, S27.1, S28.1, S29.1
P4: MCU1.18, S22.1, S23.1, S24.1, S25.1
P5: MCU1.17, S17.1, S18.1, S19.1, S20.1, S21.1
P6: MCU1.16, S1.1, S2.1, S3.1, S4.1
P7: MCU1.15, S5.1, S6.1, S7.1, S8.1, S30.1
P8: MCU1.14, S9.1, S10.1, S11.1, S12.1, S31.1
P9: D17.1, D30.1, D31.1, D32.1, MCU1.13
P10: D3.1, D7.1, D11.1, D15.1, D20.1, D24.1, D28.1, MCU1.12
P14: D1.1, D5.1, D9.1, D13.1, D18.1, D22.1, D26.1, MCU1.10
P15: D4.1, D8.1, D12.1, D16.1, D21.1, D25.1, D29.1, MCU1.9
P16: D2.1, D6.1, D10.1, D14.1, D19.1, D23.1, D27.1, MCU1.11
P19: MCU1.7, S13.1, S14.1, S15.1, S16.1, S32.1
RST: B1.2, MCU1.3
VCC: MCU1.4, TRRS1.4
dash_home: D23.2, S23.2
dash_lower: D22.2, S22.2
dash_num: D25.2, S25.2
dash_upper: D24.2, S24.2
equal_home: D27.2, S27.2
equal_lower: D26.2, S26.2
equal_num: D29.2, S29.2
equal_upper: D28.2, S28.2
mirror_five_home: D14.2, S14.2
mirror_five_lower: D13.2, S13.2
mirror_five_mod: D32.2, S32.2
mirror_five_num: D16.2, S16.2
mirror_five_upper: D15.2, S15.2
mirror_four_home: D10.2, S10.2
mirror_four_lower: D9.2, S9.2
mirror_four_mod: D31.2, S31.2
mirror_four_num: D12.2, S12.2
mirror_four_upper: D11.2, S11.2
mirror_three_home: D6.2, S6.2
mirror_three_lower: D5.2, S5.2
mirror_three_mod: D30.2, S30.2
mirror_three_num: D8.2, S8.2
mirror_three_upper: D7.2, S7.2
mirror_two_home: D2.2, S2.2
mirror_two_lower: D1.2, S1.2
mirror_two_num: D4.2, S4.2
mirror_two_upper: D3.2, S3.2
zero_home: D19.2, S19.2
zero_lower: D18.2, S18.2
zero_mod: D17.2, S17.2
zero_num: D21.2, S21.2
zero_upper: D20.2, S20.2

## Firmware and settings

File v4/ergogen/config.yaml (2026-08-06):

meta:
  engine: 4.2.1 # min; matches package.json ergogen dep

# --- Units ---
units:
  c: 14.5 # MX cutout/hole length, sized to clear the CNC corner fillet
  s: 16 # MX widest is 15.6mm
  cnc_fillet: 1 # switch cutout/recess internal corner radius for the CNC end mill
  u: U # key pitch
  # Screw-boss radius: the CNC/printed case metal each M2.5 threads into (DXF
  # reference curve, never cut into the PCB).
  screw_boss_radius: 2.75
  # Thumbcluster splay angle (deg), single source of truth: the thumb keys splay
  # by this and the thumb diodes counter-rotate by -thumb_splay to sit horizontal.
  thumb_splay: -19.20
  # Thumb diode offset from its switch in the splayed key frame. Keep
  # dx = dy * tan(thumb_splay) so it stays centered when dy changes.
  thumb_diode_dy: -4.7
  thumb_diode_dx: 1.64
  # Thumbcluster edge pad-out, separate per axis: _h is the uniform expand on the
  # _thumbbinding hull, _v trims the bottom back (see _thumbbinding).
  thumb_pad_h: 0.5
  thumb_pad_v: -0.255
  # Extra padding on the thumb cluster's inner edge ONLY (splayed-horizontal, via a
  # polygon on the inner thumb key in _thumbbinding). Pushes the inner board edge off
  # the inner mod-key pad (2mm keepout) and out to the box inner edge (closes the
  # inner-corner notch), without growing the vertical pads (which thumb_pad_h would).
  thumb_inner_pad: 0.9
  # MCU/reset/TRRS/TVS/resistor placement (off matrix_five_num, both halves).
  # x is shared per column: MCU+reset on mcu_reset_x, the rest on trrs_tvs_resistor_x.
  mcu_reset_x: 17.965
  # Seats the Liatris body outline flush with the board top edge, leaving the USB-C
  # connector mouth (which the footprint draws protruding past the body outline)
  # to overhang the edge so a cable can plug in from outside the case wall.
  mcu_y: -0.985
  reset_y: 8.065 # set for an 8mm body-edge gap below the MCU
  trrs_tvs_resistor_x: mcu_reset_x + 12.860
  trrs_y: 15.525
  # Drop the TVS so its body-edge gap up to the TRRS equals the gap down to the
  # resistor: the TVS sits symmetrically between its two neighbours (mirrors the
  # bottom gap up). Carries the resistor (defined off tvs_y) down with it.
  tvs_y: trrs_y - 21.57
  # Sets the body-edge gap below the TVS, with room for the TVS's multi-line silk
  # label plus clearance to the resistor; tvs_y mirrors this same gap above the TVS.
  resistor_y: tvs_y - 10.145
  # Silkscreen credit text offsets. Center-justified (see footprint). Pushed down to
  # sit clear below the provenance stamp, both just inside the perimeter keepout; the
  # credit then overlaps the keyswitch outlines (User.Eco1 only, never on the PCB).
  label_credit_y: 9.4
  # Pushed out to abut the perimeter keepout at the outer (pinky) edge: as far out
  # as it goes while staying clear of the keepout. Left/right tuned separately
  # (pinky differs); no vertical room (the top edge is just above).
  label_credit_x_left: -u/2 -u +24.9 # left pinky
  label_credit_x_right: u/2 -24.9 # right pinky
  # Component label y-offsets. Each label reuses its component's x var (same
  # column); hugging labels track the part's y, label_mcu_y is absolute.
  label_mcu_y: -20.55
  label_trrs_y: trrs_y - 14.27
  # TRRS pad-net labels: centered on the jack centerline (the gap between its two
  # mirrored pad columns), each level with its net's pad row. Offsets are the
  # footprint's local pad ys, which run downward, so subtract from trrs_y.
  label_trrs_gnd_y: trrs_y - 3.2 # SL pad row
  label_trrs_data_y: trrs_y - 6.2 # R2 pad row
  label_trrs_vcc_y: trrs_y - 10.75 # TP pad row
  label_tvs_y: tvs_y - 4.34
  label_resistor_y: resistor_y - 5.42
  label_reset_y: reset_y - 6.52
  # Reset pad-net label offset: GND uses +dx (right of pad column), RST -dx.
  label_reset_pad_dx: 4.5
  # Diode/socket label offset, off matrix_two_lower; tucked into the bottom-pinky
  # margin to abut the perimeter keepout at the outer and bottom edges (placement
  # rationale at the footprint).
  label_diode_x: -57.795
  label_diode_y: -24.955
  # M2.5 label offset: every screw label sits above its hole, ~2mm from the drilled-hole
  # edge (radius ~1.5mm, the actual hole on the PCB; the boss circle is case-only on
  # Eco1.User and not fabricated). Above is the one direction clear of pads and diodes for
  # all six bosses (inner/outer/center on both halves); beside or below collides on at least one.
  label_screw_dy: 4.23
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

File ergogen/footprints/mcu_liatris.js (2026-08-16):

// mcu_liatris: reversible footprint for the splitkb Liatris (RP2040) MCU.
// https://splitkb.com/products/liatris
//
// Source: derived from ceoloide/mcu_nice_nano.js by Marco Massarelli (@ceoloide),
//   https://github.com/ceoloide/ergogen-footprints, which @ceoloide built on
//   @infused-kim's nice!nano footprint. Adapted by @andornaut for the Liatris,
//   which has 5 extra bottom pins (GP12-GP16) vs the nice!nano's 3. Bottom-pin
//   positions follow the marbastlib KiCad footprint,
//   https://github.com/ebastler/marbastlib. Pinout:
//   https://docs.splitkb.com/product-guides/liatris/pinout
// License: CC-BY-NC-SA-4.0 (inherited from ceoloide/mcu_nice_nano.js).
//
// Params:
//    side: default is F for Front
//      the side on which to place the single-side footprint and designator, either F or B.
//      Cosmetic only: it sets the module layer and the designator's silk layer. It does
//      NOT affect which net reaches which MCU pin (see raw_pin_column).
//    reversible: default is false
//      if true, the footprint will be placed on both sides so that the PCB can be
//      reversible
//    raw_pin_column: default is 'front_right', either 'front_left' or 'front_right'
//      which socket column carries RAW / B+, named from the PCB front (local x -7.62
//      is 'front_left', +7.62 is 'front_right'). From the back it is the other column.
//      'front_right' is the datasheet pinout.
//      This decides which MCU pin every net reaches, so it must match how the MCU
//      seats. Wrong value: every matrix net lands on the opposite pin, and no DRC or
//      netlist check catches it. Verify by seating the module and confirming its RAW
//      pin lands on the pad silkscreened RAW.
//      Both halves of a split must use the same value: the MCU cannot be mirrored.
//    include_traces: default is true
//      if true it will include traces that connect the jumper pads to the vias
//      and the through-holes for the MCU
//    include_extra_pins: default is true
//      if true it will include the Liatris's 5 bottom pins (GP12-GP16) along with
//      their silkscreen labels. Set to false to omit them when those pins are unused,
//      which also frees up the silkscreen area below the MCU.
//    only_required_jumpers: default is false
//      if true, it will only place jumpers on the first 4 rows of pins, which can't be
//      reversed in firmware, i.e. RAW and P1, GND and P0, GND and RST, GND and VCC.
//    use_rectangular_jumpers: default is false
//      if true, it will replace chevron-style jumpers with rectangual pads
//    via_size: default is 0.8
//      allows to define the size of the via. Not recommended below 0.56 (JLCPCB minimum),
//      or above 0.8 (KiCad default), to avoid overlap or DRC errors.
//    via_drill: default is 0.4
//      allows to define the size of the drill. Not recommended below 0.3 (JLCPCB minimum),
//      or above 0.4 (KiCad default), to avoid overlap or DRC errors.
//    Pxx_label, VCC_label, RAW_label, GND_label, RST_label: default is GPIO name
//      allows to override the label for each pin
//    mcu_3dmodel_filename: default is ''
//      Allows you to specify the path to a 3D model STEP or WRL file to be
//      used when rendering the PCB. Use the ${VAR_NAME} syntax to point to
//      a KiCad configured path.
//    mcu_3dmodel_xyz_offset: default is [0, 0, 0]
//      xyz offset (in mm), used to adjust the position of the 3d model
//      relative the footprint.
//    mcu_3dmodel_xyz_scale: default is [1, 1, 1]
//      xyz scale, used to adjust the size of the 3d model relative to its
//      original size.
//    mcu_3dmodel_xyz_rotation: default is [0, 0, 0]
//      xyz rotation (in degrees), used to adjust the orientation of the 3d
//      model relative the footprint.
//
// Placement of jumpers:
//  The reversible footprint is meant to be used with jumpers on the OPPOSITE
//  side from where the Liatris (or pro-micro-compatible board) is installed. The
//  silkscreen labels match the board when read on that opposite side, so all
//  jumpers and components solder on one side while the MCU labels stay readable
//  for multimeter testing.
//
// Credits: the upstream footprint was created from scratch by @infused-kim
//  (using ideas from Albert-IV/ergogen-contrib promicro_pretty.js and
//  50an6xy06r6n/keyboard_reversible.pretty), with later improvements by @ceoloide
//  (vias closer to pads, rectangular jumpers, configurable via size, required-only
//  jumpers, single-side support, reverse-mount, both-side silk labels, KiCad 8)
//  and @andornaut (port to the splitkb Liatris).

module.exports = {
  params: {
    designator: "MCU",
    side: "F",
    reversible: false,
    raw_pin_column: "front_right",
    include_traces: true,
    include_extra_pins: true,
    only_required_jumpers: false,
    use_rectangular_jumpers: false,
    via_size: 0.8, // JLCPC min is 0.56 for 1-2 layer boards, KiCad defaults to 0.8
    via_drill: 0.4, // JLCPC min is 0.3 for 1-2 layer boards, KiCad defaults to 0.4

    show_instructions: true,
    show_silk_labels: true,
    show_silk_labels_on_both_sides: false,
    show_via_labels: true,

    mcu_3dmodel_filename: "",
    mcu_3dmodel_xyz_offset: [0, 0, 0],
    mcu_3dmodel_xyz_rotation: [0, 0, 0],
    mcu_3dmodel_xyz_scale: [1, 1, 1],

    RAW_label: "",
    GND_label: "",
    RST_label: "",
    VCC_label: "",
    P21_label: "GP29",
    P20_label: "GP28",
    P19_label: "GP27",
    P18_label: "GP26",
    P15_label: "GP22",
    P14_label: "GP20",
    P16_label: "GP23",
    P10_label: "GP21",

    P1_label: "GP0",
    P0_label: "GP1",
    P2_label: "GP2",
    P3_label: "GP3",
    P4_label: "GP4",
    P5_label: "GP5",
    P6_label: "GP6",
    P7_label: "GP7",
    P8_label: "GP8",
    P9_label: "GP9",

    GP12_label: "GP12",
    GP13_label: "GP13",
    GP14_label: "GP14",
    GP15_label: "GP15",
    GP16_label: "GP16",

    RAW: { type: "net", value: "RAW" },
    GND: { type: "net", value: "GND" },
    RST: { type: "net", value: "RST" },
    VCC: { type: "net", value: "VCC" },
    P21: { type: "net", value: "P21" },
    P20: { type: "net", value: "P20" },
    P19: { type: "net", value: "P19" },
    P18: { type: "net", value: "P18" },
    P15: { type: "net", value: "P15" },
    P14: { type: "net", value: "P14" },
    P16: { type: "net", value: "P16" },
    P10: { type: "net", value: "P10" },

    P1: { type: "net", value: "P1" },
    P0: { type: "net", value: "P0" },
    P2: { type: "net", value: "P2" },
    P3: { type: "net", value: "P3" },
    P4: { type: "net", value: "P4" },
    P5: { type: "net", value: "P5" },
    P6: { type: "net", value: "P6" },
    P7: { type: "net", value: "P7" },
    P8: { type: "net", value: "P8" },
    P9: { type: "net", value: "P9" },
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

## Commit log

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2026-03-28 Add v4 with Liatris MCU, ceoloide footprints, and project cleanup
    - Add v4 ergogen config based on v3: Liatris MCU (ceoloide/mcu_nice_nano),
    SMD diode (ceoloide/diode_tht_sod123), ceoloide/switch_mx
    - Update ceoloide submodule to latest (54a23cc)
    - Remove infused-kim submodule (unused, superseded by ceoloide)
    - Update README: add v4 to version table, fix typos (Asymmetrical,
    Steps->Step), update paths to v4, improve Installation section,
    remove stale sboysel link
    - Fix markdownlint issues: table formatting in v1/v2, disable MD013
    - Fix v3 config typo (pbboints)
    - Add .env.example
    [config.yaml]
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2026-03-28 Add custom mcu_liatris Ergogen footprint with 5 bottom pins
    - Create mcu_liatris.js based on ceoloide/mcu_nice_nano with GP12-GP16
    bottom pins, correct GPIO silkscreen labels, and marbastlib-referenced
    pin placement
    - Update Dockerfile to bake local ceoloide and custom footprints into
    ergogen-gui container at build time
    - Switch v4 config to mcu_liatris with reverse_mount enabled
    - Add microcontroller pinout tables to v3 and v4 READMEs
    - Add marbastlib to root README installation instructions
    [config.yaml, mcu_liatris.js]
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2026-06-12 Replace dotenv-cli with npm config and add TRRS data-line protection
    Use npm's built-in package.json config field for VERSION instead of
    dotenv-cli and .env, simplifying scripts and removing a dependency.
    Add TVS diode (SOD-323) and 100Ω series resistor (0603) to protect the
    MCU data pin from TRRS hot-unplug transients on both halves.
    [config.yaml]
2026-06-13 Place v4 TRRS data-line protection and update footprints
    Add the SMF3.3CA TVS (sod-123fl) and 100Ohm 0805 series resistor
    (infused-kim/smd_0805) below the TRRS jack on side B, mirrored to the
    right half, and regenerate the kicad PCBs with the new components.
    Replace the old placeholder resistor_0603/sod-323 footprints and add
    the resistor and TVS BOM entries.
    [left.kicad_pcb, right.kicad_pcb]
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2026-06-13 Fix custom diode footprint attributes and sod-123fl geometry
    After auditing the custom footprints against manufacturer outline drawings:
    - sod-123fl, sod-123w: change (attr smd) to (attr through_hole) to match
    the actual reversible hand-solder pads (resolves the SMD-vs-THT DRC/BOM
    mismatch).
    - sod-123fl: widen pads to 1.1x1.35mm for proper side fillets, widen the
    courtyard to +/-2.45mm (0.25mm pad clearance), move the silkscreen body
    lines out of the pads, and rename from the nonexistent stock name
    Diode_SMD:D_SOD-123FL to splinter:D_SOD-123FL_HandSolder.
    Re-sync the regenerated footprints into the unrouted v4/kicad boards.
    mcu_liatris pinout and geometry verified correct (incl. ag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
    [left.kicad_pcb, right.kicad_pcb]
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2026-06-13 Match sod-123fl land pattern to Nexperia SOD123FL / IPC-7351
    After a multi-source audit (Nexperia outline, Littelfuse SMF3.3 datasheet,
    IPC-7351B): set pad pitch to 3.2mm (package nominal e) to remove the
    worst-case negative-heel corner, draw the fab body at the real 3.0x1.85mm
    nominal size, and widen the courtyard to +/-2.40x+/-1.15 for IPC-nominal
    clearance over the body. Re-sync the regenerated footprint into v4/kicad.
    sod-123w and mcu_liatris verified correct; no change.
    [left.kicad_pcb, right.kicad_pcb]
2026-06-13 Finalize v4 TRRS protection placement clearance
    Move data_resistor down 0.5mm (shift_y 15-17 -> 15-17.5, both halves) so
    the TVS<->resistor courtyard gap is 0.67mm (was 0.17mm after the sod-123fl
    land-pattern update grew the TVS courtyard). All clearances verified: TVS
    0.75mm from the jack, ~28mm of open board below, both parts within the
    outline. Regenerate and re-sync v4/kicad.
    [left.kicad_pcb, right.kicad_pcb]
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2026-06-13 Finalize v4 TRRS data-on-ring wiring and fix key legends
    Swap the TRRS pinout to GND-on-sleeve / serial-data-on-ring (R2) / VCC-on-tip
    for hot-unplug resilience (sleeve breaks last, keeping a common ground), and
    update the surrounding comments to match. Correct the stale copy-pasted key
    legends on the right-hand extra 'zero' column (now 0/P/;//, verified against
    the generated PCB geometry) and drop a stray negative-zero shift.
    [config.yaml]
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2026-06-14 Fix gitignore dist pattern, stale docs, version override
    - .gitignore: ^dist$ was regex (never matched); use dist/
    - README/config: replace non-functional --VERSION override with npm pkg set
    - config.yaml: comment = key to match KC_EQL
    - remove unused .env.example
    [config.yaml]
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2026-06-14 Wire Freerouting tuning into autoroute with aggressive defaults
    autoroute.py now generates a freerouting.json (with profile.id, which fixes the startup NPE/GUI error dialog) to set the config-only scoring knobs, and passes -us/-is on the CLI. Tunable via FREEROUTING_PASSES/STRATEGY/SELECTION/VIA_COST/UNDESIRED_DIR_COST env vars; defaults bias aggressively against vias.
    [autoroute.py]
2026-06-14 Tune autoroute defaults, quiet logs, fix config-path warning
    Switch default scoring to greedy/via-cost-50 (best fully-connected, DRC-clean result; aggressive via cost only abandons nets). Add FREEROUTING_LOG_LEVEL (default WARN) driving both freerouting's console/file logs and wx's debug chatter. Pass the freerouting config dir via the --user_data_path CLI arg instead of the env var, avoiding the spurious 'Unknown settings property' warning. All knobs remain env-overridable.
    [autoroute.py]
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2026-06-14 Level v4 reset switch with adjacent mounting hole
    Align both halves' reset button y to the nearby mounting hole
    (matrix_five_home + 9.525) so the reset sits level with the screw.
    [config.yaml]
2026-06-14 Rework v4 outlines: mirrored 158x119 halves, USB at top both sides
    - Scope binding to the thumb cluster so the box governs the matrix
    outline directly (removes the top-trim subtracts).
    - Make both halves' outlines exact mirrors at 158 x 119mm. The right
    half (extra inner column) sets the width; the left mirrors it.
    - Flip the right MCU to side B so its USB faces the top edge like the
    left (mcu_liatris can't mirror in-plane; rotate:180 put USB at the
    bottom). Net P0 still maps to GP1, so firmware is unaffected.
    - Center the left half's bbox on KiCad (120,160).
    - Add reference/test outlines (outlineleft/right, testleft/right).
    [config.yaml]
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2026-06-14 Add recenter.py to v4 build; hoist column_net and placement units
    - build now runs scripts/recenter.py per generated PCB (replaces the
    inline update-pcbs step); anchor origin no longer needs fractional
    centering offsets
    - hoist constant column_net to the column level across the matrix and
    extra zones (net assignments unchanged; verified byte-for-byte equal
    generated nets per footprint)
    - factor MCU/TRRS/TVS/resistor placement into mcu_x/trrs_x/trrs_y units
    shared by both halves
    - correct misleading (side B) comment on the reversible THT data_tvs
    [config.yaml, recenter.py]
2026-06-14 Hoist v4 row_net to row level; normalize reset rotation
    - hoist constant row_net into each zone's rows block (main matrix left
    mapping, extra/thumb right mapping); mirrored keys keep their per-key
    row_net overrides
    - thumbcluster: hoist base/mirror mod-row nets to key.row_net /
    key.mirror.row_net
    - right reset rotate -90 -> 270 to match the left half's expression
    (equivalent angle)
    Generated nets verified byte-equivalent per footprint on both halves.
    [config.yaml]
2026-06-14 Mirror v4 screw zones from the left half
    Replace the three explicit right-side screw zones with mirrored copies of
    the left zones (same matrix mirror axis), so the right mounting holes are
    derived rather than manually kept in sync. Switch the per-PCB footprint
    filter from name regex to screw_left / screw_right tags (the mirror_
    prefix would otherwise make /screw_left/ match both halves); the /screw/
    name regex still drives the outline cutouts. Shared mirror/tags config
    DRYed via YAML anchors.
    Verified equivalent: mounting-hole positions, footprint nets, PCB
    Edge.Cuts, and the 3/3/6 DXF screw cutouts all unchanged.
    [config.yaml]
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2026-06-14 Fix mcu_liatris extra-pin logic, harden scripts, align ergogen version
    - mcu_liatris.js: fix dropped negation so GP12-16 extra pins emit exactly
    one block in every reversible/only_required_jumpers combination (was:
    none when reversible+!only_required, duplicate when reversible+only_required).
    Inert for v4 (reversible:false). Document the invert_pins boolean.
    - fab-jlcpcb.sh, copy-traces-routed-to-kicad.sh: set nullglob and guard the
    empty case so they print a clean message instead of failing on the literal
    unmatched glob when v4/kicad/routed/ is empty.
    - build.sh: add --init to the submodule update so a non-recursive clone
    self-initializes the vendored footprint submodules.
    - con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
    [config.yaml, mcu_liatris.js]
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2026-06-14 Fix v4 silk credit mirroring: center-justify so back copy stays on-board
    Left/right-justified reversible text mirrors about its anchor, so the
    B.SilkS copy landed off the board edge (verified via pcbnew bbox: left
    back copy at x[86.8,132.4], board starts at 130.8). Switch the credit
    text to center justification (drop align) so the mirrored back copy lands
    on the same on-board region as the front. Anchor x (credit_x_left/right
    units) centers the ~45.6mm URL ~1.5mm inside each pinky edge.
    Verified: F and B bounding boxes now coincide on-board on both halves.
    [config.yaml]
2026-06-14 Add v4 silkscreen component labels (both sides)
    Add small reversible utility_text labels identifying each non-switch
    component, placed in the gap below it on both halves (right half re-anchors
    to mirror_ refs):
    - MCU -> 'Liatris', TRRS -> 'TRRS', TVS -> 'TVS', resistor -> '100R',
    reset -> 'RESET'
    - one 'M3x0.5' per mounting hole (where: screw_left/right + adjust)
    All labels verified on-board. Component labels sit clear in component-area
    gaps; the screw labels fall in the key field (holes are between keys) so
    they clip adjacent keycaps by ~0.8-1.4mm (readable during assembly).
    [config.yaml]
2026-06-15 Refine v4 silk labels: part numbers + relocate screw labels
    - Screw labels: shrink to 0.7mm and place beside each hole instead of below
    (directly below is blocked by the key field). Anchored to each screw point
    individually (screw_left_left/center/right + mirror_) so each goes to its
    open side; no longer clips keycaps.
    - Add part numbers as a second line at reduced (0.5mm) size:
    TVS -> 'TVS / SMF3.3CA', resistor -> '100R / ERJ-6ENF1000V'
    (two-line text via escaped \n; literal newline breaks pcbnew parsing).
    - MCU label -> 'splitkb Liatris'.
    All 10 F-silk texts verified on-board, clear of keycaps and component
    courtyards on both halves.
    [config.yaml]
2026-06-15 Enlarge v4 component silk to 0.8mm; drop resistor to make room
    Bump the TVS, resistor and screw labels to 0.8mm (fab-safe min, uniform
    with the other component labels) and move parts to fit:
    - TVS label fits in-channel at 0.8, so the TVS stays at the R2 data pad
    (clamp placement preserved).
    - The resistor's part number (ERJ-6ENF1000V, ~10mm at 0.8) is too wide for
    the MCU-to-edge channel, so the resistor is dropped beside the MCU's lower
    edge (resistor_y trrs_y-21 -> trrs_y-30) and its label sits full-width
    below the MCU.
    - Screw labels 0.7 -> 0.8mm; side offset widened 4.2 -> 4.6mm to keep clear
    of the holes and keycaps.
    All 10 F-silk texts verified at 0.8mm (credit 1.2mm), on-bo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
    [config.yaml]
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2026-06-15 Add brands/part numbers to v4 reset, resistor, TVS silk labels
    - reset: 'RESET' -> 'Reset switch / E-Switch / TL3342F450QG'
    - resistor: add 'Panasonic' line -> '100R / Panasonic / ERJ-6ENF / 1000V'
    - TVS: add 'Littelfuse' line -> 'TVS / Littelfuse / SMF3.3CA'
    - Fix two stale right-half label shifts (TVS, reset) that hadn't been
    updated when the left ones moved, which put the right TVS label over the
    TVS footprint.
    All labels 0.8mm, verified on-board and collision-free on both halves.
    [config.yaml]
2026-06-15 Extract v4 silk label offsets into shared units
    Replace the literal label shift values (duplicated across left/right) with
    units: label_mcu_y, label_trrs_y, label_tvs_y, label_resistor_y,
    label_reset_y, screw_label_dx. Both halves now reference the same units (x
    reuses mcu_x/trrs_x since each label is centered on its component), so the
    left/right pairs can no longer drift apart (the bug that put the right TVS
    label over its footprint). Output unchanged.
    [config.yaml]
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2026-06-15 Remove redundant v4 silk-label comments; fix stale screw-size note
    Drop the per-unit and per-shift '# below the <component>' comments (the
    label_<component>_<axis> unit names and the section/block headers already
    convey position). Also drop the stale 'shrunk to 0.7mm' from the screw-label
    comment (they are 0.8mm now). Kept the comments that add real info
    (centered-under-component, narrow-channel split, open-side rationale).
    [config.yaml]
2026-06-15 Tighten v4 config comments
    Condense the verbose multi-line and trailing comments throughout (origin,
    mirror/source-of-truth, extra/screw zones, outline geometry, binding, TRRS/
    TVS/resistor headers, MCU side-flip, label/credit blocks, unit notes) while
    keeping the essential numbers and non-obvious rationale. Comments only.
    [config.yaml]
2026-06-15 Refactor build/routing pipeline and add GND pour + project settings stages
    - Extract shared require_pcbs helper into scripts/lib.sh; adopt it across the
    build/copy/fab wrappers (missing inputs now hard-fail consistently).
    - Port autoroute.sh to scripts/autoroute.py: with no args it routes every
    working PCB for the active version into dist/${VERSION}/kicad/freerouting/.
    - Add scripts/apply-project-settings.py (idempotent VCC net class + DRC floors
    in .kicad_pro) and run it from build.sh; pin .kicad_pro DRC floors to 0.15mm.
    - Add scripts/add-gnd-zone.py and scripts/copy-pcbs-kicad-to-routed.sh: flow a
    B.Cu GND pour onto the routed masters after routing, not at build time.
    - build.sh n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
    [add-gnd-zone.py, apply-project-settings.py, autoroute.py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]
2026-06-15 Add mcu_liatris include_extra_pins toggle; mirror v4 MCU silk labels
    - mcu_liatris gains an include_extra_pins param (default true) to omit the
    Liatris's GP12-GP16 bottom pins and their silk when unused.
    - v4 config sets show_silk_labels_on_both_sides on the MCU so the pin labels
    hidden by the reverse-mounted body also appear on the exposed side.
    [config.yaml, mcu_liatris.js]
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2026-06-15 v4 docs: add Fabrication section; error on empty lcsc
    - README: add JLCPCB Fabrication section (export flow, part-assignment
    rules, ordering steps with zip/BOM/CPL paths and DFM viewer link);
    drop the Part dimensions section
    - gen-jlcpcb-bom-cpl.py: a listed footprint with empty lcsc is now a
    hard error (exit 1, nothing written) instead of a skipped warning
    - jlcpcb-parts.json: update _comment to match the error behavior
    [gen-jlcpcb-bom-cpl.py]
2026-06-15 v4: switch data-line TVS to SMF5.0CA; refresh part labels and BOM
    Change the data-line TVS from SMF3.3CA to SMF5.0CA (5V standoff) and
    update its footprint, silk label, and jlcpcb-parts entry (C1851363).
    Refresh reset/diode/resistor silk labels and BOM notes to match the
    sourced parts, regenerate the v4 PCBs, and remove README references to
    the uncommitted AGENTS.md.
    [left.kicad_pcb, right.kicad_pcb]
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2026-06-15 v4: add component silkscreen labels
    Single-sided labels placed on each part's mount side: MCU and TRRS on
    the front, all SMD parts (diodes, resistor, TVS, reset switch) on the
    back (mirrored so they read from the back). Adds reset GND/RST pad
    labels and a diode + hotswap-socket part-number label in each half's
    bottom-pinky margin.
    [left.kicad_pcb, right.kicad_pcb]
2026-06-15 v4: solve thumbcluster splay/shift for 158x119mm board; move all component silk labels to side B
    Jointly solve the thumbcluster anchor shift and column-three splay so the
    rightmost thumb key's top-right hull corner pins to the box bottom-right corner
    and the board measures exactly 158 x 119mm. Document the coupling.
    Consolidate component silkscreen labels (MCU, TRRS, SMD parts) onto side B,
    mirrored, so they all read correctly from the back.
    [config.yaml]
2026-06-15 v4: SMD footprints with both-side routing vias; mute pcbnew noise
    Footprints:
    - Add r_0805 (single-side 0805 SMD) and convert sod-123fl from reversible
    THT to single-side SMD; both gain an opt-in include_traces_vias helper
    (via just outside each pad) plus a via_in_pad option (via in the pad,
    needs filled-and-capped vias for reflow, off by default).
    - config.yaml: data_resistor switched infused-kim/smd_0805 -> r_0805,
    data_tvs + data_resistor get include_traces_vias for both-side routing,
    and the matrix diode gets reversible + include_traces_vias so its net
    routes on either layer (single-side assembly unchanged).
    Tooling:
    - lib.sh mute_pcbnew_noise helper drops KiCad's harmless P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
    [left.kicad_pcb, right.kicad_pcb]
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2026-06-15 v4: parameterize thumb diode offset, center under switch
    Add thumb_diode_dy/dx units for the horizontal thumb diodes' offset from
    their splayed switches. dx re-centers laterally (the rotated dy would drift
    it sideways); keep dx = dy * tan(thumb_splay) so it stays centered when dy
    changes, and dx auto-flips x on the mirrored right half. Set dy to -4.7
    (sits ~4.97mm below the switch, level with the matrix diodes), centered.
    Regenerate both halves and the routed copies.
    [left.kicad_pcb, right.kicad_pcb]
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2026-06-15 v4: rework right-half matrix nets
    Remap the right half's column and row nets so the mirrored matrix and
    extra inner columns route off a different MCU bank: columns five..two ->
    P19,P8,P7,P6 plus P5,P4,P3 for the extra inner columns; rows mod/lower/
    home/upper/num -> P9/P14/P16/P10/P15. P2 (GP2) stays free for the TRRS
    serial pin; P0 (GP1), P18 (GP26), and P20 (GP28) are now unused on the
    right. Regenerate the unrouted boards; manual re-route still pending.
    [left.kicad_pcb, right.kicad_pcb]
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2026-06-16 Add JLCPCB panelization and config-provenance stamping
    panelize (scripts/panelize.{sh,py}, KiKit): combine the routed left+right
    masters into one panel-by-customer board so JLC charges its per-order PCBA
    setup + stencil fee once. DRC on the panel is advisory; the per-half
    fab-jlcpcb stays the strict gate. Shares export_jlcpcb_fab (new in
    lib.sh) with fab-jlcpcb so the kicad-cli flags and BOM/CPL join live in
    one place.
    provenance (scripts/{provenance,stamp-provenance,validate-provenance}.py):
    build stamps each board's title block (and silkscreen) with a config
    hash; validate-provenance + a fab-jlcpcb pre-gate refuse to fab a routed
    master that has drifted from config.yaml. Nudge label_credi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
    [config.yaml, panelize.py, stamp-provenance.py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]
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2026-06-16 scripts: factor shared lib.sh helpers and per-tier project settings
    Consolidate repeated wrapper logic into scripts/lib.sh:
    - require_cmds: shared dependency-presence check (fab-jlcpcb, panelize)
    - mute_pcbnew_noise / mute_kikit_noise: share one PCBNEW_NOISE pattern
    - provenance_gate_routed: shared routed/ config-drift gate
    - apply_project_settings: per-tier .kicad_pro settings, called by the step
    that writes each board set (build -> dist/, copy steps -> unrouted/routed/)
    - export_jlcpcb_fab: drop the scripts_dir arg, call helpers cwd-relative
    Standardize fab-jlcpcb and panelize on the cwd-relative ./scripts/ convention
    the rest of the pipeline already uses (drop the here variable). Use
    p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
    [add-gnd-zone.py, autoroute.py, copy-teardrops.py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]
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2026-06-16 v4: reassign left-half matrix pins, re-sync boards, harden GND guard
    config.yaml: column five left -> P15 (was P10) and swap the lower/home/
    upper row_net assignments (P14/P16/P10). Re-sync routed/ + unrouted/
    left and right boards to the new config.
    add-gnd-zone.py: exclude teardrop zones from the already-poured guard (a
    teardrop on a GND track is itself a GND zone, which made the guard see a
    pour that was never flooded and skip the real fill); clearer
    UNCHANGED/ADDED logging.
    [left.kicad_pcb, right.kicad_pcb]
2026-06-16 v4: regenerate boards with GND pour fix (JLCPCB order build)
    Re-synced unrouted + routed left/right boards. This is the build sent to
    JLCPCB: stamp built=2026-06-16T14:04:40Z config=f66b61addc4d commit=44bb610
    clean=yes.
    [left.kicad_pcb, right.kicad_pcb]
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2026-06-16 validate-fab: gate on teardrop consistency between routed halves
    The mirrored left/right masters should carry comparable teardrop counts,
    but the trace-copy workflow drops teardrops on a re-routed half, so one
    half can silently lose them. The first v4 JLCPCB order shipped this way
    (459 teardrops left vs 14 right); every existing gate passed because
    teardrops are non-functional and DRC stays clean.
    Add check 6: collect teardrop-zone counts per board, then fail any board
    below TEARDROP_MIN_FRAC (50%) of the run's best-teardropped board.
    Cross-board, evaluated after the per-board loop. Self-skips when teardrops
    are off everywhere (max count 0), so it never false-positives on an
    intentionally t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
    [validate-fab.py]
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2026-06-16 v4: restore right-half teardrops on routed + unrouted masters
    The right master carried only 20 teardrop zones (the teardrop-loss
    failure that shipped on the first JLCPCB order); re-teardropped to 502,
    now symmetric with the left half (464). Tracks, vias, and arcs are
    unchanged on both halves (408/70/128 right, 384/65/120 left); the rest
    of the diff is KiCad re-save churn. Clears the validate:fab
    teardrop-consistency gate.
    [left.kicad_pcb, right.kicad_pcb]
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2026-06-16 scripts: extract shared pcbnew-quiet import and KiKit interpreter probe
    - Add scripts/pcbnew_quiet.py and use it in route.py + validate-fab.py
    instead of duplicating the fd-2 silencing of pcbnew's startup wxASSERT.
    - Add kikit_python / kikit_importable to lib.sh; panelize.sh and
    pipeline.sh now share one interpreter resolution + import probe.
    - recenter.py: hard-fail on an unsupported page size instead of KeyError.
    - validate-fab.py: renumber the check headings to match run order.
    - README: link the custom footprints dir instead of listing names.
    [pcbnew_quiet.py, recenter.py, route.py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]
2026-06-17 v4: square-cornered USB-C notch, unified 0.25mm clearance, onshape case notes
    - config: subtract the USB-C cutout (_usbleft/_usbright) after the exterior
    fillet so the notch keeps square corners; tie it to mcu_reset_x so it tracks
    the MCU. Nudge MCU/reset/TRRS/TVS/resistor placement.
    - apply-project-settings: add ensure_default_clearance so the Default net class
    clearance is 0.25mm, unifying the gap with VCC across the board.
    - regenerate routed + unrouted boards and project files.
    - onshape: add v4 case design guidance (FDM + JLCCNC sandwich topology).
    [left.kicad_pcb, right.kicad_pcb]
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

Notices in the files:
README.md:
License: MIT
